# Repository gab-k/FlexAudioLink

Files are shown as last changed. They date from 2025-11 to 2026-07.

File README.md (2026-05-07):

# FlexAudioLink

Low-latency wireless audio bridge.

## Motivation and Use-cases

originally built as a wireless transceiver for a gaming headset retrofit. The hardware can also support:

- Wireless audio relay (e.g. room-to-room)
- BLE audio bridging (phone/laptop as central to a FlexAudioLink node)
- Flexible audio paths such as USB-to-analog, USB-to-USB, analog-to-analog, and BLE bridges

Note: Most of these are not yet implemented; see [Project Status](#project-status).

## Features

- Audio bridge endpoints: USB Audio Class device, I2S/analog codec, BLE
- Low-latency wireless link between devices
- USB CDC CLI for device configuration
- Web UI (Svelte) with WebSerial and WebSocket-to-serial bridge
- Single hardware design: nRF54LM20A + NAU88L21 + nPM1300

## Architecture

The diagram below shows the typical dongle/headset setup: dongle on the left, headset on the right. Both run the same hardware and firmware.

FlexAudioLink wireless headset use case

USB handles audio on the dongle side, I2S/codec on the headset side.

## Project Status

**Implemented:**
- USB device (UAC + CDC)
- Configuration persistence
- USB CDC CLI
- PROP radio test mode
- Audio I2S / codec integration
- Wireless audio streaming (USB ↔ I2S)

**In progress:**
- Schematic
- Update Docs

**Planned:**
- PCB layout
- Arbitrary Source/Sink combinations
- Analog multiplexing
- Packet Loss Concealment
- BLE audio transport
- Web UI

**Under evaluation:**
- Adaptive Frequency Hopping
- Clear Channel Assessment

## Documentation

[**Full documentation**](https://gab-k.github.io/FlexAudioLink/). 

Key pages:

- [**Getting Started**](https://gab-k.github.io/FlexAudioLink/getting-started/) — toolchain setup, build, and flash instructions
- [**Firmware**](https://gab-k.github.io/FlexAudioLink/firmware/) — architecture, PROP protocol
- [**Hardware**](https://gab-k.github.io/FlexAudioLink/hardware/) — schematic, PCB, rationale for chosen components
- [**Web UI**](https://gab-k.github.io/FlexAudioLink/webui/) — setup and configuration
- [**CLI Reference**](https://gab-k.github.io/FlexAudioLink/cli/) — available CLI commands

Note: the documentation is a work in progress and nowhere near complete.

## Repository Layout

- `firmware/`: active Zephyr-based firmware for `nrf54lm20dk/nrf54lm20a/cpuapp`
- `webui/`: Svelte configuration UI plus Python WebSocket-to-serial bridge
- `hardware/`: KiCad project and hardware notes
- `python/`: standalone utilities for signal generation and latency/error experiments
- `devel_notes/`: bring-up and development references

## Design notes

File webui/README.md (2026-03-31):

# FlexAudioLink Web UI

Web-based configuration GUI FlexAudioLink. Communicates with the Hardware over USB CDC ACM serial.

## Prerequisites

- [Node.js](https://nodejs.org/) >= 18
- [pnpm](https://pnpm.io/) (package manager)
- Python 3 with `pyserial` and `websockets` (only for the WebSocket bridge)

## Quick Start

```bash
cd webui/app
pnpm install
pnpm dev
```

Opens at `http://localhost:5173`. Click **Demo Mode** in the status bar to test without hardware.

## Building for Production

```bash
cd webui/app
pnpm build
```

Output goes to `webui/app/dist/`. This is a fully static site deployable to GitHub Pages or any static host.

Preview the production build locally:

```bash
pnpm preview
```

## Connecting to a Device

### Chrome / Edge (WebSerial)

Works out of the box. Click **Connect** in the status bar, then select the dongle serial port from the browser prompt.

### Firefox / Safari (WebSocket Bridge)

These browsers don't support WebSerial. Run the companion bridge script:

```bash
pip install pyserial websockets
python webui/websocket_serial_bridge.py
```

The bridge auto-detects the dongle by USB VID:PID (`1FC9:00A2`). The web app connects to `ws://localhost:8765` automatically when WebSerial is unavailable.

Bridge options:

```
python websocket_serial_bridge.py /dev/ttyACM0   # specify port
python websocket_serial_bridge.py --baud 921600   # custom baud
python websocket_serial_bridge.py --mock           # simulated device
python websocket_serial_bridge.py -v               # show serial traffic
python websocket_serial_bridge.py --list           # list serial ports
```

## Project Structure

```
webui/
  app/                          Svelte frontend
    src/
      main.js                   Entry point
      App.svelte                Shell, tab navigation
      app.css                   Global dark theme
      lib/
        stores/device.svelte.js Reactive device state, protocol parser, config validation
        transport/transport.js  WebSerial / WebSocket / Demo transport abstraction
        components/
          StatusBar.svelte      Connection status, toasts, connect/disconnect buttons
          LinkBudget.svelte     Bitrate budget, TDMA frame viz, latency estimate
        panels/
          ModePanel.svelte      Device role + operating mode selection
          StatusPanel.svelte    Live monitoring (RSSI, battery, packet loss chart)
          AudioPanel.svelte     Speaker/mic settings, EQ, codec selection
          RadioPanel.svelte     PHY rate, TX power, payload/jitter buffer config
          DevicePanel.svelte    Addressing, sleep, persistence (save/load/export/import)
          FirmwarePanel.svelte  DFU instructions with nrfutil commands
          AdvancedPanel.svelte  Raw serial console, live stats, developer shortcuts
    dist/                       Production build output (committed for GitHub Pages)
  websocket_serial_bridge.py    Python WebSocket-to-serial bridge
  spec.md                       Full design specification
```

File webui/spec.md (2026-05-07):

# Wireless Headset Configuration GUI — Design Specification

## Overview

This document describes the design and feature requirements for the web-based configuration GUI for the wireless headset + dongle system. The GUI communicates with the dongle over **USB CDC ACM** (serial) and is the primary interface for end-user configuration, advanced tuning, and firmware updates.

The GUI is delivered as a **hosted web app** (e.g. GitHub Pages) requiring zero installation for most users. It communicates with the dongle via **WebSerial** in Chromium-based browsers, or via a **local WebSocket bridge** for Firefox/Safari users. The actual UI is identical regardless of transport.

---

## Delivery Architecture

### Primary: Hosted Web App (Zero Install)

The GUI is hosted statically on **GitHub Pages** and accessed via a URL. No installation, no download, always up to date.

- Works out of the box in **Chrome, Edge, and other Chromium-based browsers** via the WebSerial API
- User clicks the link, grants serial port permission once, done
- Covers approximately 70% of desktop users

### Fallback: Local WebSocket Bridge (Firefox / Safari)

For browsers that do not support WebSerial (Firefox has no plans to implement it), a minimal companion script bridges the gap.

The bridge is a **single Python file**, runnable with no dependencies beyond PySerial and websockets:

```
pip install pyserial websockets
python websocket_serial_bridge.py
```

Once running, the web app detects WebSerial is unavailable and offers a **"Download Bridge"** button with instructions. The app then connects to `ws://localhost:8765` instead of using WebSerial directly. The protocol is identical either way — the web app does not need to know which transport it is using.

```
Chrome/Edge user:    browser ──WebSerial──────────────────── dongle USB
Firefox user:        browser ──WebSocket──┐
                                          └─ bridge.py ──── dongle USB
```

The bridge script should:
- Auto-detect the dongle by USB VID/PID
- Accept one WebSocket client at a time
- Pass text lines transparently in both directions
- Handle reconnection gracefully if the dongle is unplugged

### Frontend Stack

- **Svelte** — reactive UI with minimal boilerplate, well suited for live-updating meters and graphs
- **uPlot** — high-performance live charting for RSSI, packet loss, and throughput graphs
- **No backend server required** — fully static, GitHub Pages compatible

### Transport Abstraction

The web app should implement a simple transport interface so the rest of the code does not care whether it is talking WebSerial or WebSocket:

```javascript
// transport.js — either backend satisfies this interface
transport.send(textLine)     // sends a plain text string + newline
transport.onMessage(callback) // callback receives raw text lines
transport.connect()
transport.disconnect()
```

On page load, the app checks `navigator.serial` availability and selects the appropriate transport automatically. If neither is available, it shows a clear unsupported browser message with a link to the bridge script.

---

## Architecture Assumptions

- The dongle and headset are **identical hardware** running the **same firmware** — the role is determined entirely by the boot mode setting
- Each device has a **USB-C connector** for firmware updates, configuration, and USB audio mode
- The connected device communicates with the GUI via USB CDC ACM
- Firmware is flashed via **nrfutil** over USB serial (DFU bootloader mode); the GUI cannot flash directly but can trigger DFU mode
- Three boot modes are available: **USB Audio**, **PROP Dongle**, and **PROP Headset**
- The proprietary 2.4 GHz link uses **FHSS + TDMA** with no retransmission — missed packets are concealed via **PLC (Packet Loss Concealment)**
- USB mode turns the device into a wired USB Audio Class device — radio and codec settings do not apply
- The GUI communicates over a simple text-based CLI protocol (newline-delimited commands and responses)

---

## GUI Layout

Suggested tab or panel structure:

```
[ Mode ]  [ Status & Monitor ]  [ Audio Settings ]  [ Radio Settings ]  [ Device Settings ]  [ Firmware Update ]  [ Advanced ]
```

---

## 0. Mode Panel

Configures the fundamental operating mode of the connected device. This panel is shown first as it determines the behavior and available options of all other panels.

| Mode | Description | Effect on Other Panels |
|---|---|---|
| `usb` | Wired USB Audio Class device | Radio panel not applicable, codec settings not applicable |
| `prop_dongle` | PC-side proprietary 2.4 GHz bridge | Full access to applicable Audio and Radio settings |
| `prop_headset` | Headset-side proprietary 2.4 GHz bridge | Full access to applicable Audio and Radio settings |

**Notes:**
- Changing boot mode requires a device restart — warn the user before applying
- Both dongle and headset use the same hardware — the role is part of the persisted firmware mode

---

## 1. Status & Monitor Panel

Read-only live information. Updated on a polling interval (e.g. every 500ms).

### Device Info
- Firmware version (e.g. `v1.2.3`) — same firmware runs on both dongle and headset, role is determined by mode setting
- Peer connected (wireless): Yes / No — whether the other device in the pair is connected

### Battery
- Battery level (percentage)
- Visual battery bar indicator
- Low battery warning threshold (configurable in Device Settings)

### Link Quality
- RSSI (dBm) — live value
- Packet loss % — rolling average over last N seconds (e.g. 5s window)
- Link quality history graph — scrolling chart showing RSSI and packet loss over time (last ~60s)
- TX power currently in use (dBm)

---

## 2. Audio Settings Panel

### Speaker (Headset Output)

| Parameter | Options | Notes |
|---|---|---|
| Sample Rate | 8000, 16000, 24000, 48000, 96000 Hz | Warn if rate strains link budget |
| Bit Width | 8, 16, 24, 32 bit | Configured independently per direction. ADPCM encodes 16-bit samples only and works best up to 48 kHz. (i) tooltip shown always, with ADPCM note appended when ADPCM selected |
| Channels | Mono, Stereo | |
| Codec | PCM (uncompressed), ADPCM, LC3, Opus | See codec notes below |
| Volume | 0–100% slider | Soft volume on headset DSP |
| EQ | 5-band parametric or graphic EQ | Gain per band in dB, ±12dB range |
| Sidetone Level | 0–100% slider (0 = off) | Mic monitoring in ear, latency-critical |

### Microphone (Headset Input → PC)

| Parameter | Options | Notes |
|---|---|---|
| Sample Rate | 8000, 16000, 24000, 48000, 96000 Hz | Voice use cases rarely need >48kHz but 96kHz available for high-fidelity capture |
| Bit Width | 8, 16, 24 bit | Configured independently per direction. (i) tooltip shown always, with ADPCM note appended when ADPCM selected |
| Channels | Mono, Stereo | Stereo mic is niche but include for completeness |
| Codec | PCM, ADPCM, LC3, Opus | Should match or be independently selectable |
| Mic Gain | dB slider or stepped (e.g. 0, 6, 12, 18, 24 dB) | |
| Mic Level Meter | Live VU meter (peak + RMS) | Useful for gain staging |
| Mic Mute | Toggle button | Hardware mute preferred if supported |

### Codec Notes

| Codec | Compression Ratio | Latency Added | Quality | Notes |
|---|---|---|---|---|
| PCM | 1:1 (uncompressed) | 0ms | Perfect | Only viable at lower sample rates / mono on 4Mbps PHY |
| IMA ADPCM | 4:1 | ~0ms | Good (~78dB DR) | Recommended default, trivial complexity |
| LC3 | ~8:1 | 2.5–10ms | Excellent | Good compressed-audio candidate, Nordic SDK supported |
| Opus | Variable | 2.5–20ms | Excellent | Heavier CPU, better for music quality |

**Codec constraints enforced by the GUI:**
- ADPCM: disable bit width options other than 16-bit, cap sample rates at 48 kHz max; (i) tooltip: "ADPCM encodes 16-bit samples only and works best up to 48 kHz. Higher sample rates and other bit depths are not supported."
- LC3: sample rate locked to LC3-supported rates (8k, 16k, 24k, 32k, 48k Hz)
- PCM at 48kHz stereo 16-bit: show red budget warning immediately

### Link Budget Calculator

Displayed prominently below audio settings. Updates in real time as parameters change.

```
Speaker:  48000 Hz × 16 bit × 2 ch ÷ 4 (ADPCM) =  384 kbps
Mic:      48000 Hz × 16 bit × 1 ch ÷ 4 (ADPCM) =  192 kbps
Overhead: (framing, headers, FHSS margin)        =  ~10%
─────────────────────────────────────────────────────────
Total:                                             ~634 kbps
PHY Budget (4Mbps proprietary):                   ~3800 kbps
Headroom:                                          3166 kbps (83%)  ✅
```

- Speaker and mic share the same link pool — the calculator must treat them as a combined load
- Overhead estimate should be conservative (~10–15% for TDMA framing)
- Show a warning banner if headroom < 20%
- Show a hard error and disable "Apply" if calculated load exceeds PHY budget

### TDMA Slot Allocation

Displayed as a visual bar showing how the TDMA frame is divided between downlink (speaker) and uplink (mic). Slot allocation is **dynamic** — proportional to the bitrate ratio of speaker vs mic streams.

- TDMA frame period scales with PHY rate: 2.5ms @ 4Mbps, 5ms @ 2Mbps, 10ms @ 1Mbps
- Slot split is shown as a percentage and in milliseconds
- Updates in real time as audio settings change

### Latency Estimate

Displayed below the TDMA visualization. Shows separate one-way estimates for speaker path (PC → headset ear) and mic path (headset mic → PC). The latency model has two components:

1. **Codec frame accumulation** — zero for PCM/ADPCM (sample-level), 10ms for LC3/Opus (must buffer one full codec frame before encoding)
2. **Jitter buffer** — absorbs TDMA timing variation on the receiver side, depth is **user-configurable** in Radio Settings

Encode/decode processing time is not modeled — it is codec- and hardware-dependent and should be measured on actual hardware.

Each path is shown as a **color-coded pipeline bar** with proportional segment widths. Totals are color-coded: green (<8ms), blue (<20ms), yellow (<35ms), red (>35ms).

**Jitter buffer placement:**
- Speaker path: jitter buffer on the **headset** (receives DL data, buffers before DAC playout)
- Mic path: jitter buffer on the **dongle** (receives UL data, buffers before USB delivery)
- Capacity: configurable 1–50 ms (default: 10 ms)
- **Minimum capacity is clamped to the codec frame size** — the jitter buffer must hold at least one complete codec frame to be decodable. For LC3/Opus (10 ms frames), the minimum jitter buffer is 10 ms. For PCM/ADPCM (sample-level), the minimum is 1 ms.
- **Latency contribution = half the buffer capacity** — the target fill state is always 50% of the buffer. This is the steady-state operating point where there is equal margin to absorb both early and late packets.

**Codec frame accumulation:**

| Codec | Frame accumulation | Min jitter buffer |
|---|---|---|
| PCM | 0 ms | 1 ms |
| ADPCM | 0 ms | 1 ms |
| LC3 | 10 ms | 10 ms |
| Opus | 10 ms | 10 ms |

**Example estimates (frame accumulation + jitter buffer @ 10 ms capacity):**
- PCM/ADPCM @ 10 ms buffer: ~5 ms one-way (jitter buffer latency only: 10/2 = 5 ms)
- LC3/Opus @ 20 ms buffer: ~20 ms one-way (10 ms codec frame + 20/2 = 10 ms jitter buffer)

---

## 3. Radio Settings Panel

The Radio Settings panel includes a **live Link Budget + Latency Estimate** (same component as the Audio panel) so the user can immediately see throughput and latency implications of radio changes (PHY rate, jitter buffer, payload sizes) without switching tabs.

The operating mode (`usb` / `prop_dongle` / `prop_headset`) is selected in the **Mode panel** — the Radio panel shows the relevant settings for the currently active mode. In USB mode, a message indicates that radio settings do not apply.

### Proprietary 2.4 GHz Options

| Parameter | Options | Notes |
|---|---|---|
| PHY Data Rate | 1 Mbps, 2 Mbps, 4 Mbps | Higher = more bandwidth, potentially less range |
| TX Power | -20, -16, -12, -8, -4, 0, +4, +8 dBm | Tradeoff with battery life |
| DL Payload Size | 0.5–50 ms of audio (slider) | Speaker downlink payload in ms. GUI shows computed byte count. Max 252 bytes per packet (nRF54LM20 hw limit). Warns if ms exceeds byte limit for current audio config |
| UL Payload Size | 0.5–50 ms of audio (slider) | Mic uplink payload in ms. Independent from DL — mic and speaker streams may have very different data rates |
| Jitter Buffer | 1–50 ms of audio (slider, default 10 ms) | Receiver-side buffer capacity in ms. Latency contribution = **half the buffer capacity** (target fill state = 50%). Lower = less latency, higher = more robust |
| FHSS Channel Exclusion Map | Checkboxes or range selector per channel | Block persistent interference sources (e.g. specific WiFi channels) |
| FHSS Sequence | Auto (default) / Manual seed | Manual for advanced users |

**Notes:**
- Both payload size and jitter buffer are specified in **milliseconds of audio**, making them independent of sample rate / bit width / codec changes. The GUI computes and displays the resulting byte count for payload size.
- **Payload size is clamped to the jitter buffer capacity** — a payload larger than the buffer cannot be absorbed without overflow, causing guaranteed packet loss. The jitter buffer slider is placed above the payload sliders, and reducing the jitter buffer auto-clamps both DL/UL payloads. (i) tooltips explain this constraint on both payload sliders.
- Switching PHY data rate updates the link budget ceiling dynamically. PHY rate changes require reconnection — warn the user.
- Payload byte limit is constrained by the nRF54LM20 radio hardware: the RADIO LENGTH field is 8 bits, giving a max combined S0+LENGTH+S1+PAYLOAD of 258 bytes. With 2-byte sequence header and packet framing, the usable payload max is **252 bytes**.

## 4. Device Settings Panel

### Device Behavior
- Auto-sleep timeout (minutes): `Off / 5 / 10 / 15 / 30 / 60`
- Low battery warning threshold: `5% / 10% / 15% / 20%`

### Audio I/O
- Audio Interface: `wired` / `usb` / `codec`
- Default is set by firmware based on mode (`wired` for USB, `usb` for PROP dongle, `codec` for PROP headset)
- Setting both devices to CODEC enables analog-to-analog wireless bridging (e.g. airplane 3.5mm jack → wireless → headset)

### Radio Addressing (Proprietary 2.4 GHz)
- Device Address — this device's radio address (read from device on connect, user-editable)
- Peer Address — the address of the other device in the pair (read from device on connect, user-editable)
- Default addresses are set by firmware; the GUI reads them via `get all` on connect
- Only relevant in PROP modes; USB has no radio addressing
- For multiple pairs in the same room, configure unique address pairs to avoid crosstalk

### Persistence
- "Save to device" button — writes current config to NVM on both headset and dongle
- "Load from device" button — reads current config from device
- "Export config to file" — saves a JSON snapshot of all settings locally
- "Import config from file" — loads and applies a previously saved JSON config

---

## 5. Firmware Update Panel

Both devices have **USB-C connectors** and are flashed directly over USB. There is no wireless OTA update path.

### Update Flow
- Current firmware version displayed (from `#S fw=...` status push)
- "Enter DFU Mode" button — sends `reset dfu` to put the device into DFU bootloader
- Step-by-step instructions with copy-pasteable `nrfutil dfu usb-serial` command
- After flashing, device reboots automatically; user reconnects from GUI
- Both dongle and headset use the same firmware — to update the other device, connect it via USB-C and repeat

---

## 6. Advanced Panel

> Intended for developers and power users. Consider hiding behind a toggle or separate menu.

### PHY / Protocol Tuning
- TDMA slot timing (if configurable in firmware)
- PLC algorithm selection (if multiple are implemented — e.g. simple zero-fill vs interpolation)
- Packet size / frame duration

### Debug / Diagnostics
- Raw serial console — read-only log output from dongle/headset via CDC ACM
- Send raw command to device (text field + send button)
- Export diagnostic log to file
- Live statistics table:
  - Packets sent / received / lost (cumulative + per second)
  - RSSI histogram
  - Codec frame errors
  - Buffer underruns / overruns

### Developer Shortcuts
- Trigger headset reboot
- Trigger dongle reboot
- Enter DFU mode manually (without going through Firmware Update panel)
- Read device info dump (chip ID, MAC, build flags)

---

## GUI UX Rules

1. **Always show link budget** — it should be visible any time audio settings are on screen, not buried
2. **Greyed-out invalid options** — don't just warn, actively disable incompatible parameter combinations
3. **Apply vs Auto-apply** — audio parameter changes should require an explicit "Apply" button to avoid mid-stream glitches
4. **Unsaved changes indicator** — show a dot or asterisk in the tab title if there are unapplied or unsaved changes
5. **Connection loss handling** — if dongle disconnects mid-session, show a clear reconnect banner without crashing
6. **Mode indicator** — clearly show when USB mode disables radio controls
7. **No silent failures** — every command sent to the device should have a visible success/failure response in a status bar

---

## Serial Protocol (CDC ACM) — Text-Based CLI

The device exposes a human-readable CLI over USB CDC ACM. The same commands work identically from a terminal emulator (minicom/screen) and from the web GUI. All commands and responses are **newline-terminated plain text**.

### Commands (Host → Device)

```
get <param>              # get single param: get volume
get <group>              # get group: get audio, get radio, get device, get mode
get all                  # get everything
set <param> <value>      # set volume 80, set codec_spk adpcm
status                   # one-shot status snapshot
status on [<ms>]         # start periodic status push (default 500ms)
status off               # stop periodic push
echo on|off              # enable/disable local echo (GUI sends "echo off" on connect)
help, reset, scan, linktest  # existing firmware CLI commands, unchanged
```

Commands are **case-insensitive**. The `target` concept (dongle/headset) is gone — the firmware knows which subsystem owns each parameter.

### Responses (Device → Host)

| Pattern | Meaning | Example |
|---|---|---|
| `OK param=value` | Set succeeded | `OK volume=80` |
| `ERR param reason` | Set failed | `ERR codec_spk invalid value "mp3"` |
| `key=value` | Get response (one per line) | `volume=80` |
| `[groupname]` | Group header (human readability aid, GUI ignores) | `[audio]` |
| `#S key=val key=val ...` | Periodic status push (space-separated) | `#S rssi=-62 bat=87 loss=0.1 conn=yes` |
| anything else | Raw console text | Passed to debug console in Advanced panel |

### Status Push Abbreviated Keys

| Key | Meaning |
|---|---|
| `rssi` | RSSI in dBm |
| `bat` | Battery percentage |
| `loss` | Packet loss percentage |
| `conn` | Peer connected (yes/no) |
| `tx` | Packets transmitted (cumulative) |
| `rx` | Packets received (cumulative) |
| `lost` | Packets lost (cumulative) |
| `urun` | Buffer underruns |
| `orun` | Buffer overruns |
| `cerr` | Codec errors |
| `fw` | Firmware version |

### Parameter Table

| Parameter | Group | Type | Values |
|---|---|---|---|
| `sample_rate_spk` | audio | int | 8000..96000 |
| `bit_width_spk` | audio | int | 8,16,24,32 |
| `channels_spk` | audio | string | mono,stereo |
| `codec_spk` | audio | string | pcm,adpcm,lc3,opus |
| `volume` | audio | int | 0..100 |
| `sidetone` | audio | int | 0..100 |
| `sample_rate_mic` | audio | int | 8000..96000 |
| `bit_width_mic` | audio | int | 8,16,24 |
| `channels_mic` | audio | string | mono,stereo |
| `codec_mic` | audio | string | pcm,adpcm,lc3,opus |
| `mic_gain` | audio | int | 0..60 |
| `mic_mute` | audio | bool | on/off |
| `eq` | audio | special | `set eq <band> <freq> <gain>`, get returns `eq0=100,0` etc. |
| `phy_rate` | radio | int | 1,2,4 |
| `tx_power` | radio | int | -20..8 |
| `fhss_exclusion` | radio | list | comma-separated ints or `none` |
| `payload_ms_dl` | radio | float | 0.5..50 |
| `payload_ms_ul` | radio | float | 0.5..50 |
| `jitter_buffer_ms` | radio | float | 1..100 |
| `audio_io` | device | string | wired,usb,codec |
| `device_addr` | radio | hex | 4-byte address, e.g. `0xD0D0D0D0` |
| `peer_addr` | radio | hex | 4-byte address of peer device |
| `mode` | mode | string | usb,prop_dongle,prop_headset |
| `auto_sleep` | device | int | 0..60 |
| `low_battery_threshold` | device | int | 0..100 |

### GUI Connect Sequence

On successful serial/WebSocket connection, the GUI sends:

```
echo off
status on 500
get all
```

This suppresses local echo, starts periodic status pushes at 500ms, and requests the full current configuration.

---

## Out of Scope for v1

- Mobile app / BLE configuration (considered v2)
- Cloud firmware hosting / auto-update checking
- Multi-device management (more than one headset)
- Per-application audio modes (OS-level integration)
- Noise cancellation controls (requires DSP firmware support)
- Native desktop app (Tauri/Electron) — the web app + bridge covers all use cases without the complexity

---

## Open Questions / To Be Decided in Firmware

- Which PLC algorithm(s) will be implemented?
- Is sidetone processed on the headset CODEC or in firmware?
- Are EQ coefficients computed on-device or sent as pre-calculated biquad coefficients from the GUI?
- What is the exact TDMA frame duration and how does that map to minimum/maximum configurable latency?
- Is there a hardware mute button on the headset, and does it report state back over the wireless link?

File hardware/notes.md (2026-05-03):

# Hardware Notes

## ICs
- **SoC** nRF54LM20A-PAAA (CSP47)
- **Codec** NAU88L21 (QFN32)
- **PMIC** nPM1300-QEAA
- **Battery protection** DW01A + FS8205

---

## Power Rails
| Rail | Source | Voltage | Load |
|---|---|---|---|
| Buck 1 (VOUT1) | VBAT/VBUS | 1.8V | nRF VDD, codec VDDB |
| Buck 2 (VOUT2) | VBAT/VBUS | 3.3V | codec VDDMIC, LDO1 in |
| LDO 1 | Buck 2 | 1.8V | codec VDDA |
| LDO 2 | Buck 2 | TBD | touch IC / reserved |

---

## nRF54LM20A — Schematic Reminders
- DC-DC: DCC node → **L1 4.7µH 0603**
- VDD bulk: **C4 10µF 0402** + **C5 100nF 0201**
- VDD decoupling: **C1, C2, C10 100nF 0201**
- DECA: **FB1 0201** + **FB2 0201** (two ferrites in DK) + **C6 4.7µF** to VSS
- DECD: **C14 2.2µF 0201** to VSS
- DECRF: **L5 1.0nH** + **C8 1.0pF** + **C7 2.2µF** (DK fits C7, ref design marks N.C.)
- DECUSB: **C10 2.2µF + C11 4.7µF**
- USB VBUS: **R1 2R2 0603** in series; ESD protection PRTR5V0U2F + CMC DLM0NSM900HY2D on D+/D−
- TRXTUNE: **R2 200R 0603** to VSS
- 32MHz XO: XTAL_2016 (X1)
- 32.768kHz XO: XTAL_2012 (X2) — optional
- RF match: L2 3.6nH, L3 4.7nH, L4 3.3nH, C3 1.2pF, C12 1.5pF, C13 N.C.

## nRF54LM20A — Layout Reminders
- Follow Nordic reference: **13.11 × 12.00mm**, 8-layer, 1.57mm total
- RF matching as close as possible to ANT pin
- DECRF caps closest to IC, then L5
- DECA/DECD/DCC passives same side as IC, short traces
- P2 is high-speed port — follow Nordic HDI rules

---

## NAU88L21 — Schematic Reminders
- VDDA: 1.8V from LDO1 (max 1.98V — do not exceed)
- VDDB: 1.8V from Buck 1
- VDDMIC: 3.3V from Buck 2
- VREF: **4.7µF** low-leakage cap to VSSA
- Charge pump caps: **3× 2µF ceramic** (CPCA–CPCB, CPOUTP, CPOUTN)
- Mic inputs: AC-coupled differential
- I2S to nRF: BCLK, FS, DACIN, ADCOUT
- I2C to nRF: SCLK, SDIO (codec is slave)
- GPIO1/CSB: pull low → I2C addr 0x1B, pull high → 0x54

---

## nPM1300 — Schematic Reminders
- Buck inductors: **L6, L7 = 2.2µH** (one per buck)
- VSET1: **47k** → 1.8V startup
- VSET2: **4.7k** → 1.8V startup (change for 3.3V per resistor table)
- VSYS bulk: **4× 10µF** caps (PVSS1 and PVSS2, via to GND plane on each)
- VOUT1 decoupling: **10µF + 100nF**
- VOUT2 decoupling: **10µF + 100nF**
- VBUS input: **4.7µF + 100nF**; ferrite bead FB on VBUS line
- CC1/CC2: wire directly to USB-C connector + **1.0nF cap to GND** on each
- NTC pin: connect battery thermistor (10k NTC recommended)
- VBAT: via DW01A + FS8205 from cell
- VDDIO: connect to Buck 1 output (1.8V)
- nPM1300 communicates with nRF via I2C (SCL/SDA)

---

## Battery Protection (DW01A + FS8205)
- Cell+ → DW01A → FS8205 → VBAT (nPM1300)
- Skip if using cell with integrated protection PCB

---

## USB-C Connector
- VBUS → ferrite bead (120R/3A) → nPM1300 VBUS
- VBUS → R1 2R2 → nRF VBUS pin
- CC1/CC2 → nPM1300 CC1/CC2 (+ 1.0nF to GND each)
- D+/D− → ESD + CMC → nRF P2 (high-speed port)
- R45/R46 5k1 on CC lines only needed if doing USB-C orientation detection at nRF — not required for basic charging

---

## Codec Audio Path
- Headphone out: HPL/HPR ground-referenced, cap-free
- Mic in: MICL+/− or MICR+/− AC-coupled differential
- Digital mic alt: MICR−/DMCLK + MICL−/DMDATA

---

## Analog Multiplexing

To support arbitrary Source/Sink configurations on the 3.5 mm jack, the physical connector needs to be routable to either the codec's DAC output (headphone driver) or ADC input (mic stage) under firmware control.

### Option 1 — Cable adapter (early prototyping)
- Route the source's headphone out to the codec's mic input via a custom cable.
- No hardware changes required.
- Caveats: shifts burden to the user, mic input impedance/gain is not ideal for line-level signals, inconsistent with the "same hardware, different roles" design goal.

### Option 2 — Analog switch IC (production)
- Add analog multiplexer between the 3.5 mm jack and the codec's audio pins.
- Firmware controls the switch via GPIO to swap the jack between HPL/HPR (DAC out) and MICL+/MICR+ (ADC in).
- Combined with I2S stream routing in firmware, any audio endpoint becomes reconfigurable as source or sink.

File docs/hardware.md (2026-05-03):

# Hardware

The `hardware/` directory currently contains early hardware notes and KiCad work-in-progress.

## Target Design

The current design plan is based on:

| Component | Description |
|---|---|
| nRF54LM20A | Nordic SoC with BLE and proprietary radio |
| NAU88L21 | Audio codec |
| nPM1300 | PMIC |

!!! note
    Hardware is in early concept stage, subject to change.

## Schematic & Layout

KiCad project files are in `hardware/`. Refer to the schematic and layout for pin assignments and component details.

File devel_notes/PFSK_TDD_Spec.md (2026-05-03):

# PFSK Time Division Duplex Spec

Implementation reference: `firmware/src/prop_fsk/`.

- `radio_core.c`:

	authoritative for radio timing and DMA ownership.
	Its entirely Timer/[DPPI](https://docs.nordicsemi.com/bundle/ps_nrf54LM20A/page/dppi.html) and ISR based.

- `session.c`:

	is authoritative for service state, app queues, payload sequencing, and loss accounting.

## Protocol

- Both peers run identical half-duplex ping-pong logic.
- No role-specific slot timing exists.
- Device waits for RX to be done then sends itself, then listens again.
- A TX turn always sends either one queued payload packet or one keepalive.
- Listen timeouts include random jitter; the first peer to time out transmits, breaking deadlock.

## Relevant RADIO Peripheral Events

Reference: [nRF RADIO peripheral docs](https://docs.nordicsemi.com/bundle/ps_nrf54LM20A/page/radio.html)

| Event | Meaning |
|---|---|
| `ADDRESS` | Address field sent or matched |
| `PHYEND` | Full packet (including CRC) transmitted or received |
| `CRCOK` | Received packet CRC matched |
| `CRCERROR` | Received packet CRC failed |

Handled inside `radio_isr`.

## Radio Turn State

Active protocol states:

| State | Meaning |
|---|---|
| `LISTEN` | Radio waits for peer `ADDRESS` or listen deadline. |
| `IN_RX` | Peer packet has reached `ADDRESS`; RX deadline is armed. |
| `IN_TX` | Local TX has been committed; late peer `ADDRESS` is ignored. |

Implementation sentinel:

| State | Meaning |
|---|---|
| `DISABLED` | Radio path stopped; not a protocol turn. |

## Session Events

`radio_core` emits one ordered event stream to `session.c`.

```c
struct pfsk_session_event {
	enum pfsk_session_event_type type;
	uint32_t tick;
	int16_t rssi_dbm;
};
```

| Event | Tick | Notes |
|---|---|---|
| `RX_OK` | RX `PHYEND` | RSSI valid. |
| `RX_BAD` | RX `PHYEND` | RSSI valid. |
| `TX_END` | TX `PHYEND` | TX already ended. |
| `RX_INCOMPLETE` | deadline | RX packet did not finish in time. |
| `LISTEN_TIMEOUT` | deadline | No peer `ADDRESS` before deadline. |
| `TX_TRIGGER_FAILED` | deadline | Timeout TX could not be triggered. |

## Packet Format

Packet struct:

```c
struct pfsk_packet {
	uint8_t  length;
	uint16_t seq;
	uint8_t  payload[PFSK_PAYLOAD_MAX_LEN];
} __packed __aligned(4);
```

- packets never use `seq = PFSK_KEEPALIVE_SEQ = UINT16_MAX` unless they are keepalive packets.
- zero-length app TX frames are invalid

Constants:
- `PFSK_PACKET_METADATA_LEN = 2U`
- `PFSK_PAYLOAD_MAX_LEN = 252`
- `PFSK_KEEPALIVE_PAYLOAD_LEN = 16U`
- `PFSK_KEEPALIVE_SEQ = UINT16_MAX`

Note: Do not confuse `payload` inside `struct pfsk_packet` with `PAYLOAD` field inside [nRF RADIO Peripheral docs -> Packet configuration](https://docs.nordicsemi.com/bundle/ps_nrf54LM20A/page/radio.html#ariaid-title2)

## Buffers

`radio_core.c` owns the packet buffers. `PACKETPTR` always points to the
current read/write slot in these rings. The RADIO peripheral DMA transfers
directly to/from the pointed-to ring entry.

```c
tx_ring[PFSK_RADIO_TX_RING_DEPTH]
rx_ring[PFSK_RADIO_RX_RING_DEPTH]
keepalive_packet
```

Ring ownership:

| Ring index | Writer |
|---|---|
| TX write | session thread |
| TX read | radio ISR |
| RX write | radio ISR |
| RX read | session thread |

Rings are Single Producer Single Consumer (SPSC). One slot remains unused to distinguish full from empty.

TX ring rules:

- TX ring contains payload packets only.
- Keepalives are never queued in the TX ring.
- Session gets a pointer to the next TX slot via `pfsk_radio_tx_get_wr_ptr()`,
  copies into it, then commits with `pfsk_radio_tx_advance_wr_idx()`.
- Session-thread does not touch `PACKETPTR`.

RX ring rules:

- RADIO DMA writes to `rx_ring[rx_wr_idx]`.
- `CRCOK`/`CRCERROR` queues a session event.
- RX write index advances only if the RX ring has room and event queueing succeeds.
- Session releases a consumed RX slot with `pfsk_radio_rx_advance_rd_idx()`.

## RADIO Shortcuts

Reference: [nRF RADIO peripheral docs -> SHORTS register](https://docs.nordicsemi.com/bundle/ps_nrf54LM20A/page/radio.html#ariaid-title112)

Base shorts (always active):

- `READY_START` - READY -> START: begin TX/RX as soon as ramp-up completes.
- `PHYEND_DISABLE` - PHYEND -> DISABLE: shut down radio after every packet.
- `ADDRESS_RSSISTART` - ADDRESS -> RSSISTART: sample signal strength on peer packet arrival.

Turn-selection shorts (one active at a time):

- `DISABLED_RXEN` - DISABLED -> RXEN: after disable, ramp back into RX.
- `DISABLED_TXEN` - DISABLED -> TXEN: after disable, ramp into TX.

`PHYEND_DISABLE` + a turn-selection short chains the whole turnaround in hardware:
packet ends -> radio disables -> radio re-enables in the next direction, no ISR needed.

The active shortcut set prepares the *next* direction:

- while receiving: `BASE | DISABLED_TXEN` (turnaround into TX)
- while transmitting: `BASE | DISABLED_RXEN` (turnaround into RX)

## PACKETPTR and Shortcut Programming

PACKETPTR and shortcuts are always set together. Programming an RX pointer selects `DISABLED_TXEN`, programming a TX pointer selects `DISABLED_RXEN`.

RX programming:

```text
PACKETPTR = &rx_ring[rx_wr_idx]
```

TX programming:

```text
PACKETPTR = &tx_ring[tx_rd_idx]   if TX ring non-empty
PACKETPTR = &keepalive_packet     if TX ring empty
```

Programming points:

| Point | Action |
|---|---|
| `pfsk_radio_start()` | Program initial RX pointer. |
| `ADDRESS` while `LISTEN` | Program next TX pointer. |
| `LISTEN`/`IN_RX` timeout | Program TX pointer directly before switchover to TX. |
| `ADDRESS` while `IN_TX` | Program next RX pointer. |

## Deadlines

Timer:

- TIMER10 runs at 1 MHz.
- CC[2] captures `ADDRESS`.
- CC[3] is the semantic deadline compare.
- CC[4] captures `PHYEND`.

Constants:
- `PFSK_RADIO_LISTEN_TIMEOUT_BASE_US` — fixed listen window before timeout.
- `PFSK_RADIO_LISTEN_TIMEOUT_JITTER_US` — max random offset added to listen timeout. Determined by xorshift PRNG seeded from device ID and cycle counter.
- `PFSK_RADIO_MAX_PACKET_AIRTIME_US` — worst-case packet duration on air.
- `PFSK_RADIO_DEADLINE_MIN_LEAD_US` — minimum time a deadline must be in the future.

Deadline rules:

| Entry | Deadline |
|---|---|
| start -> `LISTEN` | `now + BASE_US + jitter` |
| `ADDRESS` -> `IN_RX` | `address_tick + MAX_PACKET_AIRTIME_US` |
| TX `PHYEND` -> `LISTEN` | `tx_phyend_tick + MAX_PACKET_AIRTIME_US + jitter` |

If a deadline is too close, `radio_core` clamps it forward by
`DEADLINE_MIN_LEAD_US` and increments `deadline_late_count`.

TX ring publication never changes deadlines.

## State Transitions

### `LISTEN -> IN_RX`

Trigger: RADIO `ADDRESS`.

Actions:

- set `turn_state = IN_RX`
- arm RX deadline
- program TX `PACKETPTR` to TX ring head or keepalive

### `LISTEN -> IN_TX`

Trigger: listen timeout deadline.

Actions:

- queue `LISTEN_TIMEOUT`
- program TX `PACKETPTR` to TX ring head or keepalive
- set shorts to `DISABLED_TXEN`
- clear pending `ADDRESS`, RX ADDRESS could arrive between timeout and `DISABLE`
- set `turn_state = IN_TX`
- trigger RADIO `DISABLE`
- if trigger fails, queue `TX_TRIGGER_FAILED`

### `IN_RX -> IN_TX`

Triggers:

- RX `PHYEND`, after `CRCOK`/`CRCERROR`
- RX timeout deadline

RX `PHYEND` actions:

- `CRCOK` queues `RX_OK`; `CRCERROR` queues `RX_BAD`
- RX write index advances if event queueing succeeds
- `PHYEND` handler sets `turn_state = IN_TX`
- hardware short starts TX

RX timeout deadline actions:

- queue `RX_INCOMPLETE`
- program TX `PACKETPTR` to TX ring head or keepalive
- set shorts to `DISABLED_TXEN`
- clear pending `ADDRESS`, RX ADDRESS could arrive between timeout and `DISABLE`
- set `turn_state = IN_TX`
- trigger RADIO `DISABLE`
- if trigger fails, queue `TX_TRIGGER_FAILED`

### `IN_TX -> LISTEN`

Trigger: TX `PHYEND`.

Actions:

- advance TX read index only if the transmitted packet came from TX ring buffer
- set `turn_state = LISTEN`
- arm post-TX listen deadline
- increment TX stats
- queue `TX_END`

`TX_END` is queued from `PHYEND`, not from `DISABLED`. The next RX pointer was
already programmed by TX `ADDRESS`.

## Session Handling

`RX_OK`:

- read RX packet from RX ring
- reject malformed length and advance RX read index (early return)
- reset `consecutive_rx_misses`
- enter `IN_SERVICE`
- if keepalive marker: no app frame, no seq accounting
- if payload: queue app RX frame and update seq/loss accounting
- advance RX read index

`RX_BAD`:

- reset `consecutive_rx_misses`
- advance RX ring buffer read index
- do not enter service from `NO_SERVICE`

`RX_INCOMPLETE`:

- increment `rx_incomplete_count`
- reset `consecutive_rx_misses`

`LISTEN_TIMEOUT`:

- if `IN_SERVICE`, increment `consecutive_rx_misses`
- if threshold reached, mark `NO_SERVICE`
- if already `NO_SERVICE`, log rate-limited waiting warning

`TX_END`:

- refill TX ring with queued payloads until full or app TX queue empty

`TX_TRIGGER_FAILED`:

- increment `tx_trigger_fail_count`
- mark `NO_SERVICE`
- log error
- stop radio path

## Service State

States:

- `NO_SERVICE`
- `IN_SERVICE`

Enter service:

- valid `RX_OK` packet, including keepalive

Stay in service:

- `RX_OK`, `RX_BAD`, and `RX_INCOMPLETE` all reset misses
- `RX_BAD` and `RX_INCOMPLETE` reset misses but do not enter service on their own

Leave service:

- only consecutive `LISTEN_TIMEOUT` events count as missed peer activity
- threshold is `PFSK_SESSION_SYNC_LOSS_TURNS`

On service loss:

- increment outage counter if previously in service
- reset miss counter
- clear in-service timestamp
- clear RX sequence continuity
- do not reset radio turn state

## Responsibilities

`radio_core` owns:

- RADIO/TIMER configuration
- turn state
- deadlines and jitter
- `PACKETPTR` and shorts
- RX/TX rings
- keepalive fallback packet
- session event queue
- hardware stats

`session.c` owns:

- service state
- app TX/RX queues
- payload copy into TX ring
- payload sequence/loss accounting
- user-visible session stats/logs

## Invariants

1. Both roles use identical timing logic.
2. `PHYEND` anchors packet end.
3. `ADDRESS` is the only peer packet start gate.
4. `FRAMESTART` and `SYNC` are not protocol inputs.
5. `session.c` does not own radio turn state.
6. Session events do not carry packet payloads.
7. TX ring entries are payload-only.
8. Empty TX ring means transmit `keepalive_packet`.
9. Keepalive does not consume payload sequence numbers.
10. Payload sequence generation skips `PFSK_KEEPALIVE_SEQ`.
11. Session-thread TX publication does not program `PACKETPTR`.
12. `PACKETPTR` and turn-selection shortcut are always programmed together.
13. `ADDRESS` must program the next-direction `PACKETPTR` before `PHYEND` fires.
14. Only `RX_OK` can enter service; `RX_BAD` and `RX_INCOMPLETE` cannot.
15. Listen timeout is a hard turn boundary.
16. Stop purges stale session events and leaves radio state disabled.

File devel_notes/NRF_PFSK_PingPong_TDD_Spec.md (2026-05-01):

# nRF PFSK Ping-Pong TDD Spec

Implementation reference: `firmware/src/prop_fsk/`.

`radio_core.c` is authoritative for radio timing and DMA ownership. `session.c`
is authoritative for service state, app queues, payload sequencing, and loss
accounting.

## Protocol

- Both peers run identical half-duplex ping-pong logic.
- `ADDRESS` is the only early RX-start gate.
- `PHYEND` is the packet-end timing anchor.
- `FRAMESTART` and `SYNC` are not used for core state transitions.
- No role-specific slot timing exists.
- A TX turn always sends either one queued payload packet or one keepalive.

## Radio Turn State

Active protocol states:

| State | Meaning |
|---|---|
| `LISTEN` | Radio waits for peer `ADDRESS` or listen deadline. |
| `IN_RX` | Peer packet has reached `ADDRESS`; RX deadline is armed. |
| `IN_TX` | Local TX has been committed; late peer `ADDRESS` is ignored. |

Implementation sentinel:

| State | Meaning |
|---|---|
| `DISABLED` | Radio path stopped; not a protocol turn. |

`session.c` must not duplicate this state machine.

## Radio Events

`radio_core` emits one ordered metadata-only event stream to `session.c`.

```c
struct pfsk_radio_event {
	enum pfsk_radio_event_type type;
	uint32_t tick;
	int16_t rssi_dbm;
};
```

Events never carry packets. RX packets are read from the RX ring.

| Event | Tick | Notes |
|---|---|---|
| `RX_OK` | RX `PHYEND` | RSSI valid. |
| `RX_BAD` | RX `PHYEND` | RSSI valid. |
| `TX_END` | TX `PHYEND` | TX already ended. |
| `RX_INCOMPLETE` | deadline | RX packet did not finish in time. |
| `LISTEN_TIMEOUT` | deadline | No peer `ADDRESS` before deadline. |
| `TX_TRIGGER_FAILED` | deadline | Timeout TX could not be triggered. |

## Packet Format

RADIO config:

- `lflen = 8`
- `s0len = 0`
- `s1len = 0`

DMA buffer:

```text
offset 0:    LENGTH byte
offset 1..N: PAYLOAD bytes, N = LENGTH
```

Packet struct:

```c
struct pfsk_packet {
	uint8_t  length;
	uint16_t seq;
	uint8_t  data[PFSK_PAYLOAD_MAX_LEN];
} __packed __aligned(4);
```

Constants:

- `PFSK_PACKET_METADATA_LEN = 2U`
- `PFSK_PAYLOAD_MAX_LEN = 252`
- max transmitted `length = 254`
- `PFSK_KEEPALIVE_PAYLOAD_LEN = 16U`
- `PFSK_KEEPALIVE_SEQ = UINT16_MAX`
- `PFSK_KEEPALIVE_LEN = PFSK_PACKET_METADATA_LEN + PFSK_KEEPALIVE_PAYLOAD_LEN`
- keepalive `length = PFSK_KEEPALIVE_LEN`
- payload packets never use `PFSK_KEEPALIVE_SEQ`
- zero-length app TX frames are invalid

## Buffers

`radio_core.c` owns the packet buffers:

```c
g_tx_ring[PFSK_RADIO_TX_RING_DEPTH]
g_rx_ring[PFSK_RADIO_RX_RING_DEPTH]
g_keepalive_packet
```

Ring ownership:

| Ring index | Writer |
|---|---|
| TX write | session thread |
| TX read | radio ISR |
| RX write | radio ISR |
| RX read | session thread |

Rings are SPSC. One slot remains unused to distinguish full from empty.

TX ring rules:

- TX ring contains payload packets only.
- Keepalives are never queued in the TX ring.
- Session publishes a payload by filling `pfsk_radio_tx_get_wr_ptr()` and then
  calling `pfsk_radio_tx_advance_wr_idx()`.
- Session-thread publication does not touch `PACKETPTR`.

RX ring rules:

- RADIO DMA writes to `g_rx_ring[g_rx_wr_idx]`.
- `CRCOK`/`CRCERROR` queues a metadata-only event.
- RX write index advances only if the RX ring has room and event queueing
  succeeds.
- Session releases a consumed RX slot with `pfsk_radio_rx_advance_rd_idx()`.

## RADIO Shortcuts

Base shorts:

- `READY_START`
- `PHYEND_DISABLE`
- `ADDRESS_RSSISTART`

Turn-selection shorts:

- `DISABLED_RXEN`
- `DISABLED_TXEN`

The active shortcut set is:

- RX path: `BASE | DISABLED_RXEN`
- TX path: `BASE | DISABLED_TXEN`

## PACKETPTR Rules

RX programming:

```text
PACKETPTR = &g_rx_ring[g_rx_wr_idx]
```

TX programming:

```text
PACKETPTR = &g_tx_ring[g_tx_rd_idx] if TX ring non-empty
PACKETPTR = &g_keepalive_packet     if TX ring empty
```

Programming points:

| Point | Action |
|---|---|
| `pfsk_radio_start()` | Program initial RX pointer. |
| `ADDRESS` while `LISTEN` | Program next TX pointer. |
| `LISTEN`/`IN_RX` timeout | Program TX pointer directly before switchover to TX. |
| `ADDRESS` while `IN_TX` | Program next RX pointer. |

## Deadlines

Timer:

- TIMER10 runs at 1 MHz.
- CC[2] captures `ADDRESS`.
- CC[3] is the semantic deadline compare.
- CC[4] captures `PHYEND`.

Deadline rules:

| Entry | Deadline |
|---|---|
| start -> `LISTEN` | `now + BASE_US + jitter` |
| `ADDRESS` -> `IN_RX` | `address_tick + MAX_PACKET_AIRTIME_US` |
| TX `PHYEND` -> `LISTEN` | `tx_phyend_tick + MAX_PACKET_AIRTIME_US + jitter` |

`radio_core` clamps too-late deadlines forward by
`PFSK_RADIO_DEADLINE_MIN_LEAD_US` and increments `deadline_late_count`.

TX ring publication never changes deadlines.

## State Transitions

### `LISTEN -> IN_RX`

Trigger: RADIO `ADDRESS`.

Actions:

- set `turn_state = IN_RX`
- arm RX deadline
- program TX `PACKETPTR` to TX ring head or keepalive
- set shorts to `BASE | DISABLED_TXEN`

### `LISTEN -> IN_TX`

Trigger: listen timeout deadline.

Actions:

- queue `LISTEN_TIMEOUT`
- program TX `PACKETPTR` to TX ring head or keepalive
- clear pending `ADDRESS`
- set `turn_state = IN_TX`
- trigger RADIO `DISABLE`
- if trigger fails, queue `TX_TRIGGER_FAILED`

### `IN_RX -> IN_TX`

Triggers:

- RX `PHYEND`, after `CRCOK`/`CRCERROR`
- RX timeout deadline

RX `PHYEND` actions:

- `CRCOK` queues `RX_OK`; `CRCERROR` queues `RX_BAD`
- RX write index advances if event queueing succeeds
- `PHYEND` handler sets `turn_state = IN_TX`
- hardware short starts TX

RX timeout deadline actions:

- queue `RX_INCOMPLETE`
- program TX pointer
- set `turn_state = IN_TX`
- trigger RADIO `DISABLE`

### `IN_TX -> LISTEN`

Trigger: TX `PHYEND`.

Actions:

- advance TX read index only if the transmitted packet came from TX ring buffer
- set `turn_state = LISTEN`
- arm post-TX listen deadline
- increment TX stats
- queue `TX_END`

`TX_END` is queued from `PHYEND`, not from `DISABLED`. The next RX pointer was
already programmed by TX `ADDRESS`.

## Session Handling

`RX_OK`:

- read RX packet from RX ring
- reject malformed length and release slot
- reset `consecutive_rx_misses`
- enter `IN_SERVICE`
- if keepalive marker: no app frame, no seq accounting
- if payload: queue app RX frame and update seq/loss accounting
- release RX slot

`RX_BAD`:

- reset `consecutive_rx_misses`
- release RX slot
- do not enter service from `NO_SERVICE`

`RX_INCOMPLETE`:

- increment `rx_incomplete_count`
- reset `consecutive_rx_misses`

`LISTEN_TIMEOUT`:

- if `IN_SERVICE`, increment `consecutive_rx_misses`
- if threshold reached, mark `NO_SERVICE`
- if already `NO_SERVICE`, log rate-limited waiting warning

`TX_END`:

- refill TX ring with queued payloads until full or app TX queue empty

`TX_TRIGGER_FAILED`:

- increment `tx_trigger_fail_count`
- mark `NO_SERVICE`
- log error
- stop radio path

## Service State

External states:

- `NO_SERVICE`
- `IN_SERVICE`

Enter service:

- valid `RX_OK` packet, including keepalive

Stay in service:

- `RX_OK`, `RX_BAD`, and `RX_INCOMPLETE` all reset misses

Leave service:

- only consecutive `LISTEN_TIMEOUT` events count as missed peer activity
- threshold is `PFSK_SESSION_SYNC_LOSS_TURNS`

On service loss:

- increment outage counter if previously in service
- reset miss counter
- clear in-service timestamp
- clear RX sequence continuity
- do not reset radio turn state

## Responsibilities

`radio_core` owns:

- RADIO/TIMER configuration
- turn state
- deadlines and jitter
- `PACKETPTR` and shorts
- RX/TX rings
- keepalive fallback packet
- metadata-only radio event queue
- hardware stats

`session.c` owns:

- service state
- app TX/RX queues
- payload copy into TX ring
- payload sequence/loss accounting
- keepalive RX policy
- user-visible session stats/logs

## Invariants

1. Both roles use identical timing logic.
2. `PHYEND` anchors packet end.
3. `ADDRESS` is the only peer packet start gate.
4. `FRAMESTART` and `SYNC` are not protocol inputs.
5. `session.c` does not own radio turn state.
6. RX events do not carry packet payloads.
7. TX ring entries are payload-only.
8. Empty TX ring means transmit `g_keepalive_packet`.
9. Keepalive does not consume payload sequence numbers.
10. Payload sequence generation skips `PFSK_KEEPALIVE_SEQ`.
11. Session-thread TX publication does not program `PACKETPTR`.
12. Listen timeout is a hard turn boundary.
13. Stop purges stale radio events and leaves radio state disabled.

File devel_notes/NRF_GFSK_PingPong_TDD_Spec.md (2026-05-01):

# nRF GFSK Ping-Pong TDD Spec

Implementation reference: `firmware/src/prop_gfsk/`.

`radio_hw.c` is authoritative for radio timing and DMA ownership. `link.c`
is authoritative for service state, app queues, payload sequencing, and loss
accounting.

## Protocol

- Both peers run identical half-duplex ping-pong logic.
- `ADDRESS` is the only early RX-start gate.
- `PHYEND` is the packet-end timing anchor.
- `FRAMESTART` and `SYNC` are not used for core state transitions.
- No role-specific slot timing exists.
- A TX turn always sends either one queued payload packet or one keepalive.

## Hardware Turn State

Active protocol states:

| State | Meaning |
|---|---|
| `LISTEN` | Radio waits for peer `ADDRESS` or listen deadline. |
| `IN_RX` | Peer packet has reached `ADDRESS`; RX deadline is armed. |
| `IN_TX` | Local TX has been committed; late peer `ADDRESS` is ignored. |

Implementation sentinel:

| State | Meaning |
|---|---|
| `DISABLED` | Radio path stopped; not a protocol turn. |

`link.c` must not duplicate this state machine.

## Hardware Events

`radio_hw` emits one ordered metadata-only event stream to `link.c`.

```c
struct pgfsk_hw_event {
	enum pgfsk_hw_event_type type;
	uint32_t tick;
	int16_t rssi_dbm;
};
```

Events never carry packets. RX packets are read from the RX ring.

| Event | Tick | Notes |
|---|---|---|
| `RX_OK` | RX `PHYEND` | RSSI valid. |
| `RX_BAD` | RX `PHYEND` | RSSI valid. |
| `TX_END` | TX `PHYEND` | TX already ended. |
| `RX_INCOMPLETE` | deadline | RX packet did not finish in time. |
| `LISTEN_TIMEOUT` | deadline | No peer `ADDRESS` before deadline. |
| `TX_TRIGGER_FAILED` | deadline | Timeout TX could not be triggered. |

## Packet Format

RADIO config:

- `lflen = 8`
- `s0len = 0`
- `s1len = 0`

DMA buffer:

```text
offset 0:    LENGTH byte
offset 1..N: PAYLOAD bytes, N = LENGTH
```

Packet struct:

```c
struct pgfsk_packet {
	uint8_t  length;
	uint16_t seq;
	uint8_t  data[PGFSK_PAYLOAD_MAX_LEN];
} __packed __aligned(4);
```

Constants:

- `PGFSK_PACKET_METADATA_LEN = 2U`
- `PGFSK_PAYLOAD_MAX_LEN = 252`
- max transmitted `length = 254`
- `PGFSK_KEEPALIVE_PAYLOAD_LEN = 16U`
- `PGFSK_KEEPALIVE_SEQ = UINT16_MAX`
- `PGFSK_KEEPALIVE_LEN = PGFSK_PACKET_METADATA_LEN + PGFSK_KEEPALIVE_PAYLOAD_LEN`
- keepalive `length = PGFSK_KEEPALIVE_LEN`
- payload packets never use `PGFSK_KEEPALIVE_SEQ`
- zero-length app TX frames are invalid

## Buffers

`radio_hw.c` owns the packet buffers:

```c
g_tx_ring[PGFSK_HW_TX_RING_DEPTH]
g_rx_ring[PGFSK_HW_RX_RING_DEPTH]
g_keepalive_packet
```

Ring ownership:

| Ring index | Writer |
|---|---|
| TX write | link thread |
| TX read | radio ISR |
| RX write | radio ISR |
| RX read | link thread |

Rings are SPSC. One slot remains unused to distinguish full from empty.

TX ring rules:

- TX ring contains payload packets only.
- Keepalives are never queued in the TX ring.
- Link publishes a payload by filling `pgfsk_hw_tx_get_wr_ptr()` and then
  calling `pgfsk_hw_tx_advance_wr_idx()`.
- Link-thread publication does not touch `PACKETPTR`.

RX ring rules:

- RADIO DMA writes to `g_rx_ring[g_rx_wr_idx]`.
- `CRCOK`/`CRCERROR` queues a metadata-only event.
- RX write index advances only if the RX ring has room and event queueing
  succeeds.
- Link releases a consumed RX slot with `pgfsk_hw_rx_advance_rd_idx()`.

## RADIO Shortcuts

Base shorts:

- `READY_START`
- `PHYEND_DISABLE`
- `ADDRESS_RSSISTART`

Turn-selection shorts:

- `DISABLED_RXEN`
- `DISABLED_TXEN`

The active shortcut set is:

- RX path: `BASE | DISABLED_RXEN`
- TX path: `BASE | DISABLED_TXEN`

## PACKETPTR Rules

RX programming:

```text
PACKETPTR = &g_rx_ring[g_rx_wr_idx]
```

TX programming:

```text
PACKETPTR = &g_tx_ring[g_tx_rd_idx] if TX ring non-empty
PACKETPTR = &g_keepalive_packet     if TX ring empty
```

Programming points:

| Point | Action |
|---|---|
| `pgfsk_hw_start()` | Program initial RX pointer. |
| `ADDRESS` while `LISTEN` | Program next TX pointer. |
| `LISTEN`/`IN_RX` timeout | Program TX pointer directly before switchover to TX. |
| `ADDRESS` while `IN_TX` | Program next RX pointer. |

## Deadlines

Timer:

- TIMER10 runs at 1 MHz.
- CC[2] captures `ADDRESS`.
- CC[3] is the semantic deadline compare.
- CC[4] captures `PHYEND`.

Deadline rules:

| Entry | Deadline |
|---|---|
| start -> `LISTEN` | `now + BASE_US + jitter` |
| `ADDRESS` -> `IN_RX` | `address_tick + MAX_PACKET_AIRTIME_US` |
| TX `PHYEND` -> `LISTEN` | `tx_phyend_tick + MAX_PACKET_AIRTIME_US + jitter` |

`radio_hw` clamps too-late deadlines forward by
`PGFSK_HW_DEADLINE_MIN_LEAD_US` and increments `deadline_late_count`.

TX ring publication never changes deadlines.

## State Transitions

### `LISTEN -> IN_RX`

Trigger: RADIO `ADDRESS`.

Actions:

- set `turn_state = IN_RX`
- arm RX deadline
- program TX `PACKETPTR` to TX ring head or keepalive
- set shorts to `BASE | DISABLED_TXEN`

### `LISTEN -> IN_TX`

Trigger: listen timeout deadline.

Actions:

- queue `LISTEN_TIMEOUT`
- program TX `PACKETPTR` to TX ring head or keepalive
- clear pending `ADDRESS`
- set `turn_state = IN_TX`
- trigger RADIO `DISABLE`
- if trigger fails, queue `TX_TRIGGER_FAILED`

### `IN_RX -> IN_TX`

Triggers:

- RX `PHYEND`, after `CRCOK`/`CRCERROR`
- RX timeout deadline

RX `PHYEND` actions:

- `CRCOK` queues `RX_OK`; `CRCERROR` queues `RX_BAD`
- RX write index advances if event queueing succeeds
- `PHYEND` handler sets `turn_state = IN_TX`
- hardware short starts TX

RX timeout deadline actions:

- queue `RX_INCOMPLETE`
- program TX pointer
- set `turn_state = IN_TX`
- trigger RADIO `DISABLE`

### `IN_TX -> LISTEN`

Trigger: TX `PHYEND`.

Actions:

- advance TX read index only if the transmitted packet came from TX ring buffer
- set `turn_state = LISTEN`
- arm post-TX listen deadline
- increment TX stats
- queue `TX_END`

`TX_END` is queued from `PHYEND`, not from `DISABLED`. The next RX pointer was
already programmed by TX `ADDRESS`.

## Link Handling

`RX_OK`:

- read RX packet from RX ring
- reject malformed length and release slot
- reset `consecutive_rx_misses`
- enter `IN_SERVICE`
- if keepalive marker: no app frame, no seq accounting
- if payload: queue app RX frame and update seq/loss accounting
- release RX slot

`RX_BAD`:

- reset `consecutive_rx_misses`
- release RX slot
- do not enter service from `NO_SERVICE`

`RX_INCOMPLETE`:

- increment `rx_incomplete_count`
- reset `consecutive_rx_misses`

`LISTEN_TIMEOUT`:

- if `IN_SERVICE`, increment `consecutive_rx_misses`
- if threshold reached, mark `NO_SERVICE`
- if already `NO_SERVICE`, log rate-limited waiting warning

`TX_END`:

- refill TX ring with queued payloads until full or app TX queue empty

`TX_TRIGGER_FAILED`:

- increment `tx_trigger_fail_count`
- mark `NO_SERVICE`
- log error
- stop radio path

## Service State

External states:

- `NO_SERVICE`
- `IN_SERVICE`

Enter service:

- valid `RX_OK` packet, including keepalive

Stay in service:

- `RX_OK`, `RX_BAD`, and `RX_INCOMPLETE` all reset misses

Leave service:

- only consecutive `LISTEN_TIMEOUT` events count as missed peer activity
- threshold is `PGFSK_LINK_SYNC_LOSS_TURNS`

On service loss:

- increment outage counter if previously in service
- reset miss counter
- clear in-service timestamp
- clear RX sequence continuity
- do not reset hardware turn state

## Responsibilities

`radio_hw` owns:

- RADIO/TIMER configuration
- turn state
- deadlines and jitter
- `PACKETPTR` and shorts
- RX/TX rings
- keepalive fallback packet
- metadata-only hardware event queue
- hardware stats

`link.c` owns:

- service state
- app TX/RX queues
- payload copy into TX ring
- payload sequence/loss accounting
- keepalive RX policy
- user-visible link stats/logs

## Invariants

1. Both roles use identical timing logic.
2. `PHYEND` anchors packet end.
3. `ADDRESS` is the only peer packet start gate.
4. `FRAMESTART` and `SYNC` are not protocol inputs.
5. `link.c` does not own hardware turn state.
6. RX events do not carry packet payloads.
7. TX ring entries are payload-only.
8. Empty TX ring means transmit `g_keepalive_packet`.
9. Keepalive does not consume payload sequence numbers.
10. Payload sequence generation skips `PGFSK_KEEPALIVE_SEQ`.
11. Link-thread TX publication does not program `PACKETPTR`.
12. Listen timeout is a hard turn boundary.
13. Stop purges stale hardware events and leaves hardware state disabled.

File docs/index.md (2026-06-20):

# FlexAudioLink Documentation

- [Getting Started](getting-started.md) — toolchain setup, build, and flash instructions
- [Firmware](firmware/index.md) — firmware architecture, audio path, radio timing, and latency measurements
- [Hardware](hardware.md) — schematic, PCB, rationale for chosen components
- [Web UI](webui.md) — setup and configuration
- [CLI Reference](cli.md) — available CLI commands

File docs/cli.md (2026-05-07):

# CLI Reference

The nRF firmware exposes a USB CDC CLI in `firmware/src/cli.c`.

## Commands

| Command | Description |
|---|---|
| `help` | Show available commands |
| `get` | Get current configuration |
| `set mode <usb\|prop_dongle\|prop_headset>` | Set the boot mode |
| `status` | Show device status |
| `status on [ms]` | Enable periodic status output with optional interval |
| `status off` | Disable periodic status output |
| `scan` | Run a BLE/prop scan |
| `linktest on\|off\|status` | Control link test mode |
| `i2s tone on\|off\|status` | Control I2S tone generator |
| `reset` | Reset the device |

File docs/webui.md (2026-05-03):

# Web UI

The `webui/` directory contains:

- a **Svelte application** in `webui/app/`
- a **Python WebSocket-to-serial bridge** in `webui/websocket_serial_bridge.py`

## Communication

The UI communicates with the device over USB CDC ACM using:

- **WebSerial** in Chromium-based browsers
- a local **WebSocket bridge** for browsers without WebSerial support

!!! warning
    `webui/spec.md` is broader than the currently implemented firmware surface and should be read as intent rather than as a statement of completed firmware behavior.

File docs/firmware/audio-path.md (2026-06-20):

# Audio Path

Audio path code owns the PCM routing selected by `app_control` at boot. PROP is
treated as a packet service here; radio/TDD internals are covered in
[PROP TDD](prop-tdd.md), and codec-facing PCM transport is covered in
[I2S/TDM](i2s-tdm.md).

## Source Files

| File | Ownership |
|---|---|
| `firmware/src/app_control.c` | Selects the boot mode and initializes the matching path. |
| `firmware/src/audio/path_common.*` | Shared path state names, level filter, PI controller, global fixed/auto FLL state, and PROP audio packet-size symbols. |
| `firmware/src/audio/path_wired.c` | Direct USB audio to codec path. |
| `firmware/src/audio/path_dongle.c` | USB audio to PROP path for the dongle. |
| `firmware/src/audio/path_headset.c` | PROP audio to codec path for the headset. |
| `firmware/src/usb/usb_audio.*` | TinyUSB audio FIFO adapter and audio reset helper. |
| `firmware/src/audio/i2s.*` | I2S/TDM activation API and codec-facing transport thread. |

## Path Matrix

| Mode | Path | Speaker flow | Mic flow | Buffer/FLL |
|---|---|---|---|---|
| `usb` | `path_wired` | USB EP OUT FIFO -> I2S TX | I2S RX left mono -> USB EP IN FIFO | Uses `BUFFERING` / `PLAYING` and FLL PI control. |
| `prop_dongle` | `path_dongle` | USB EP OUT FIFO -> PROP TX queue | PROP RX queue -> USB EP IN FIFO | No I2S, codec, buffering state, or FLL control. |
| `prop_headset` | `path_headset` | PROP RX queue -> speaker FIFO -> I2S TX | I2S RX left mono -> mic FIFO -> PROP TX queue | Uses `BUFFERING` / `PLAYING` and FLL PI control. |

The active path is derived from the persisted `app_control` mode. The CLI
`set mode <usb|prop_dongle|prop_headset>` command saves the new mode and
reboots; paths are not hot-swapped without reboot.

## Audio Units

The fixed PCM geometry lives in `firmware/src/audio/audio_config.h`.
Speaker audio is 48 kHz, 16-bit, stereo PCM; microphone audio is 48 kHz,
16-bit, mono PCM after the I2S layer extracts the left channel.

Important derived units:

| Symbol | Meaning |
|---|---|
| `AUDIO_SPK_TARGET_BYTES` | Target speaker buffer level used to start I2S-backed paths and close the FLL loop. |
| `AUDIO_SPK_BUFFER_BYTES` | Local headset speaker FIFO capacity. |
| `AUDIO_MIC_BUFFER_BYTES` | Local headset mic FIFO capacity. |
| `AUDIO_I2S_BLOCK_BYTES` | I2S DMA block size and speaker transfer unit. |
| `PROP_SPK_PACKET_BYTES` | One PROP speaker payload. |
| `PROP_MIC_PACKET_BYTES` | One PROP mic payload. |

## Buffer States

Buffer states are only used by the I2S-backed paths: `path_wired` and
`path_headset`. `path_dongle` does not maintain `BUFFERING` / `PLAYING`; it
moves USB and PROP payloads whenever complete payloads are available.

| State | Meaning |
|---|---|
| `PATH_STATE_BUFFERING` | Path is waiting for enough speaker data before activating I2S. |
| `PATH_STATE_PLAYING` | Path has activated I2S and is feeding speaker blocks. |

Wired and headset paths use the same state rule shape: start playback when the
speaker FIFO plus pending I2S bytes reaches `AUDIO_SPK_TARGET_BYTES`, and return
to buffering when pending I2S data has drained and the speaker FIFO has less
than one full `AUDIO_I2S_BLOCK_BYTES` block. Returning to buffering increments
`spk_underrun_events`.

## Runtime Behavior

`path_wired`:

- Waits for TinyUSB audio EP OUT and EP IN FIFOs.
- Uses the USB speaker FIFO directly as the I2S TX source.
- Starts I2S when USB speaker level plus I2S pending bytes reaches
  `AUDIO_SPK_TARGET_BYTES`.
- Stops I2S and increments `spk_underrun_events` when playback drains below one
  I2S block.
- Retunes the codec FLL while playing.

`path_dongle`:

- Waits for TinyUSB audio EP OUT and EP IN FIFOs.
- Reads USB speaker data in `PROP_SPK_PACKET_BYTES` chunks and enqueues PROP TX
  packets.
- Dequeues PROP RX packets with `PROP_MIC_PACKET_BYTES` payloads and writes them
  to the USB mic FIFO.
- Counts speaker bytes consumed from USB after a PROP TX enqueue failure in
  `overflow_bytes`.

`path_headset`:

- Creates local TinyUSB-style speaker and mic FIFOs with `tu_fifo_config()`.
- Moves PROP speaker packets into the local speaker FIFO.
- Starts I2S when speaker FIFO plus pending I2S bytes reaches
  `AUDIO_SPK_TARGET_BYTES`.
- Sends complete mic payloads from the local mic FIFO to PROP TX.
- Retunes the codec FLL while playing.

## PROP Audio Payloads

Audio paths enqueue and dequeue `struct prop_packet` objects through the PROP
session API. `prop_packet.length` includes `PROP_PACKET_METADATA_LEN`; audio
payload size is `packet.length - PROP_PACKET_METADATA_LEN`.

| Direction | Payload size |
|---|---|
| Dongle -> Headset speaker | `PROP_SPK_PACKET_BYTES` |
| Headset -> Dongle mic | `PROP_MIC_PACKET_BYTES` |

The audio payload does not carry a stream ID or duplicate byte count. Direction
is implied by the active device role.

## FLL Controller

The I2S-backed path threads monitor speaker level while playing and run the FLL
controller when automatic FLL mode is active:

| Input | Use |
|---|---|
| Path target | Desired total speaker level in bytes. |
| Software FIFO level | Current path-owned speaker FIFO level. |
| I2S pending level | Bytes submitted to the I2S pipeline and not yet matched by RX completion. |

Each path periodically filters `fifo + pending` with
`codec_level_filter_update()`. On the FLL update interval, it passes
`AUDIO_SPK_TARGET_BYTES` and `AUDIO_SAMPLE_RATE_HZ` to
`codec_clock_controller()`. The controller computes buffer error, derives
warning levels from the target, applies PI control, and calls
`nau88l21_set_fll_target_rate_hz()` with `AUDIO_SAMPLE_RATE_HZ - adjust_hz`.

`fll_set_fixed()` pauses automatic updates by setting a global fixed target;
`fll_set_auto()` resumes automatic control. FLL control is unavailable in
`prop_dongle` mode because that path does not use the codec or I2S.

## USB Audio Adapter

Audio paths read and write TinyUSB endpoint FIFOs directly:

| Direction | FIFO accessor |
|---|---|
| Speaker source | `tud_audio_get_ep_out_ff()` |
| Microphone sink | `tud_audio_get_ep_in_ff()` |

`usb_audio_reset()` restores nominal feedback and clears the audio endpoint
FIFOs. USB audio callbacks wake `path_wired` or `path_dongle` depending on the
current mode.

## CLI Status

`status_audio on [ms]` enables periodic `#A ...` lines. `status_audio off`
disables them.

`usb` and `prop_headset` report the shared codec path status:

- `state`
- `spk_fifo_bytes`
- `spk_pending_bytes`
- `spk_filtered_level_bytes`
- `spk_error_bytes`
- `spk_p_adjust_hz`
- `spk_i_adjust_hz`
- `spk_fll_target_rate_hz`
- `spk_underruns`

`prop_dongle` reports:

- `overflow_bytes`

## Constraints

- Audio format is fixed by compile-time constants; it is not negotiated per
  path.
- Speaker samples are stereo; captured I2S samples are reduced to mono by
  keeping the left channel in the I2S layer.
- The active path is selected at boot from persisted mode.
- PROP audio uses fixed speaker and mic packet sizes.
- Path modules do not implement packet-loss concealment.

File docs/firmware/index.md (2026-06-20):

# Firmware Overview

FlexAudioLink firmware is a Zephyr application for
`nrf54lm20dk/nrf54lm20a/cpuapp`. `main.c` only enters `app_control_boot()`;
long-running work is handled by subsystem threads such as USB, CLI, I2S, PROP,
and the active audio path.

## Module Map

| Module | Purpose | Source files |
|---|---|---|
| `app_control` | Loads persisted boot mode, starts the selected path, and gates USB startup. | `firmware/src/app_control.c`, `firmware/src/main.c` |
| Audio path | Mode-specific audio routing and buffer control. | `firmware/src/audio/path_common.*`, `path_wired.c`, `path_dongle.c`, `path_headset.c` |
| I2S/TDM | Codec-facing PCM transport thread and Zephyr I2S driver owner. | `firmware/src/audio/i2s.*` |
| NAU88L21 | I2C codec init, clock-master setup, headphone DAC bring-up, FLL retune API. | `firmware/src/audio/nau88l21.*` |
| TinyUSB device | USBHS startup, TinyUSB task loop, and mode-dependent descriptors for UAC+CDC or CDC-only enumeration. | `firmware/src/usb/usb_device.c`, `usb_descriptors.c`, `tusb_config.h` |
| USB audio | UAC endpoint FIFOs and UAC control requests. | `firmware/src/usb/usb_audio.c`, `usb_audio.h` |
| CDC CLI | USB CDC transport, command parser, and status emitter. | `firmware/src/usb/usb_cdc.c`, `firmware/src/cli.c` |
| PROP subsystem | Proprietary radio session queues and radio/TDD engine. Treat as one subsystem from audio code. | `firmware/src/prop/session.*`, `radio_core.*` |

See [PROP TDD](prop-tdd.md) for radio turn timing, packet ownership, and
`session.c` / `radio_core.c` coupling.

## Firmware References

- [Audio Path](audio-path.md) describes mode-specific routing, buffering, PROP
  audio payloads, FLL control, USB audio integration, and CLI audio status.
- [I2S/TDM](i2s-tdm.md) describes codec-facing PCM transport, DMA blocks,
  pending-byte accounting, and the nRF TDM configuration.
- [NAU88L21 Codec](nau88l21-codec.md) describes codec initialization, clock
  master setup, headphone output bring-up, and FLL retuning.
- [PROP TDD](prop-tdd.md) describes radio turn timing, packet ownership,
  queueing, and loss accounting.
- [Latency Measurement](latency_measurement.md) records the measured downstream
  firmware/device latency from dongle marker GPIO to headset analog output.

## Boot Modes

`app_control_boot()` initializes Zephyr settings, reads `mode/active`, defaults
to `usb`, and starts one route:

| Mode | Started modules | Audio route |
|---|---|---|
| `usb` | `path_wired_init()` | USB speaker -> I2S/TDM -> codec, codec RX -> USB mic |
| `prop_dongle` | `prop_session_start_dongle()`, `path_dongle_init()` | USB speaker -> PROP, PROP -> USB mic |
| `prop_headset` | `prop_session_start_headset()`, `path_headset_init()` | PROP -> I2S/TDM -> codec, codec RX -> PROP |

The USB device thread waits on `app_control_await_boot()` before TinyUSB
initialization. Mode changes are persisted by the CLI and require reboot.

## Runtime Ownership

| Owner | Runtime resources |
|---|---|
| `app_control` | Current mode enum and settings key `mode/active`. |
| Audio path threads | Route-local state, TinyUSB FIFO access, PROP session queue use, buffer/FLL status. |
| I2S thread | `tdm` device, TX/RX DMA slabs, I2S command queue, pending-byte counter. |
| NAU88L21 driver | `i2c23` device pointer after init and FLL fractional register writes. |
| USB device thread | USBHS low-level init, TinyUSB task loop, UAC/CDC descriptors. |
| CLI thread | Command queue, async output queue, periodic link/audio status output. |
| PROP subsystem | Radio packet rings, app-facing PROP queues, session status and loss accounting. |

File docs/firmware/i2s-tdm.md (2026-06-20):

# I2S/TDM

`firmware/src/audio/i2s.*` owns the Zephyr I2S/TDM device and presents a FIFO
based PCM transport to the audio path modules.

## Purpose

Move fixed-size PCM blocks between path-owned FIFO objects and the nRF TDM
peripheral.

## Source Files

| File | Role |
|---|---|
| `firmware/src/audio/i2s.c` | I2S thread, Zephyr I2S config, DMA slabs, active/inactive loop. |
| `firmware/src/audio/i2s.h` | I2S activation API; includes the shared PCM constants from `audio_config.h`. |
| `firmware/prj.conf` | Enables I2S and sets TX/RX TDM block counts. |
| `firmware/boards/nrf54lm20dk_nrf54lm20a_cpuapp.overlay` | TDM pins, DMA RAM region, 32 MHz reference clock output. |

## Buffers

| Direction | FIFO contract |
|---|---|
| Speaker TX | Reads complete stereo PCM blocks of `AUDIO_I2S_BLOCK_BYTES` from the path-provided TX FIFO. |
| Mic RX | Writes a mono chunk containing one left-channel sample per stereo frame to the path-provided RX FIFO. |

## Ownership

The I2S thread owns the `tdm` device, TX/RX DMA slabs, command queue, running
flag, and pending-byte counter. Audio path modules own the `tu_fifo_t` objects
passed into `audio_i2s_activate()`.

The FIFO type is always TinyUSB's `tu_fifo_t`, even when the active path is not
using USB audio. In headset mode, USB enumerates CDC-only, but `path_headset`
still defines local static speaker and mic FIFOs with `tu_fifo_config()`. This
lets wired and headset playback use the same I2S buffering contract: the I2S
layer only sees a TX FIFO and an RX FIFO, not whether those FIFOs are USB
endpoint FIFOs or local path buffers.

## PCM Geometry

| Symbol | Meaning |
|---|---|
| `AUDIO_SAMPLE_RATE_HZ` | Fixed PCM frame rate used by USB, I2S, PROP sizing, and codec FLL targeting. |
| `AUDIO_I2S_CHANNELS` | Number of TDM/I2S slots. |
| `AUDIO_BITS_PER_SAMPLE` | Bits per channel sample. |
| `AUDIO_I2S_BYTES_PER_FRAME` | Bytes per interleaved I2S stereo sample pair. |
| `AUDIO_I2S_BYTES_PER_MS` | Derived byte rate for stereo PCM. |
| `AUDIO_I2S_BLOCK_BYTES` | DMA block size and speaker FIFO transfer unit. |
| `AUDIO_I2S_SAMPLE_PAIRS_PER_BLOCK` | Interleaved L/R sample pairs per DMA block. |

## Stereo To Mono

The TDM/codec interface is configured as stereo, but the firmware exports mic
audio as mono. `audio_i2s_rx_block()` calls `extract_left_to_mono()` on every
RX block before writing to the path RX FIFO.

The extraction copies the left channel sample from each interleaved stereo
frame into the front of the same slab block, then writes the resulting mono
chunk to the RX FIFO. The right channel is ignored. Keeping this conversion in
the I2S layer means `path_wired` and `path_headset` both receive the same mono
mic FIFO format; neither path needs to understand the codec stereo slot layout.

## Public API

| Function | Behavior |
|---|---|
| `audio_i2s_activate(tx_fifo, rx_fifo)` | Enqueues an activate command with path-owned FIFOs. |
| `audio_i2s_deactivate()` | Enqueues a deactivate command. |
| `audio_i2s_tx_get_pending_bytes()` | Returns speaker bytes submitted to I2S and not yet matched by RX completion. |

The command queue depth is one. Calls block if the command slot is full.
Current implementation requires both `tx_fifo` and `rx_fifo` to be non-null.

## Thread Startup

`K_THREAD_DEFINE(audio_i2s_thread_id, ...)` starts the I2S thread at boot.

Startup sequence:

1. Verify `tdm` and `i2c23` devices are ready.
2. Initialize the NAU88L21 codec over I2C.
3. Configure Zephyr I2S TX and RX directions.
4. Wait for an activate command.

## Zephyr I2S Config

Both directions use:

| Field | Value |
|---|---|
| `word_size` | `AUDIO_BITS_PER_SAMPLE` |
| `channels` | `AUDIO_I2S_CHANNELS` |
| `format` | `I2S_FMT_DATA_FORMAT_I2S` |
| `frame_clk_freq` | `AUDIO_SAMPLE_RATE_HZ` |
| `block_size` | `AUDIO_I2S_BLOCK_BYTES` |
| `options` | `I2S_OPT_BIT_CLK_SLAVE \| I2S_OPT_FRAME_CLK_SLAVE` |

The I2S config `timeout` field differs by direction:

| Direction | Timeout |
|---|---|
| TX | `0` / no wait |
| RX | `SYS_FOREVER_MS` |

DMA memory comes from static slabs:

| Slab | Block size | Block count |
|---|---:|---:|
| TX | `AUDIO_I2S_BLOCK_BYTES` | `CONFIG_I2S_NRF_TDM_TX_BLOCK_COUNT` |
| RX | `AUDIO_I2S_BLOCK_BYTES` | `CONFIG_I2S_NRF_TDM_RX_BLOCK_COUNT` |

The board overlay reserves a `DMA_RAM` region for TDM and TWIM EasyDMA.

## Active Loop

On activation:

- Pre-fill TX by submitting every full `AUDIO_I2S_BLOCK_BYTES` block currently
  available.
- Trigger `I2S_TRIGGER_START` for both directions.
- Retry start in a bounded prepare/start loop.

While active:

- Check for a queued deactivate command.
- Block on `i2s_read()` for the next RX block.
- Decrement pending TX bytes by one block after RX completion.
- Extract left channel to mono and write it to the RX FIFO.
- Submit all complete `AUDIO_I2S_BLOCK_BYTES` blocks available from the TX FIFO.

On stop or error, the thread issues `I2S_TRIGGER_DROP`, clears the running flag,
and resets pending bytes to zero.

## Pending Byte Accounting

`audio_i2s_tx_pending_bytes` increments by `AUDIO_I2S_BLOCK_BYTES` after each
successful `i2s_write()`. It decrements by the same amount after each
successful `i2s_read()`.

Audio path code adds this value to the speaker FIFO count so buffer control
includes both software-buffered audio and audio already committed to DMA/I2S.

## Codec Clock Relationship

Only codec-master clocking is supported:

- nRF TDM is BCLK/LRCK slave.
- The board drives MCLKI to the NAU88L21 from nRF PCLK.
- NAU88L21 FLL output generates the codec master clocks.
- Audio paths retune the codec FLL, which changes the I2S consume rate.

See [NAU88L21 Codec](nau88l21-codec.md) for clock and FLL details.

## Constraints

- PCM geometry is fixed by compile-time audio constants.
- One active path at a time.
- RX and TX progress are treated as paired for pending-byte accounting.
- Microphone data exported by this layer is left-channel mono only.

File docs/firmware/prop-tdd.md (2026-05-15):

# PROP Time Division Duplex

PROP — proprietary 2.4 GHz FSK link layer. TDD half-duplex: both peers share one channel, alternating TX/RX. No fixed slot assignment; listen timeout with random jitter resolves contention. Idle peer transmits keepalive or queued payload on timeout.

Implementation reference: `firmware/src/prop/`

- `radio_core.c` — authoritative for radio timing and DMA ownership. Entirely Timer/[DPPI](https://docs.nordicsemi.com/bundle/ps_nrf54LM20A/page/dppi.html) and ISR based.
- `session.c` — authoritative for service state, app queues, payload sequencing, and loss accounting.

## Protocol

- Both peers run identical half-duplex ping-pong logic.
- No role-specific slot timing exists.
- Device waits for RX to be done then sends itself, then listens again.
- A TX turn always sends either one queued payload packet or one keepalive.
- Listen timeouts include random jitter; the first peer to time out transmits, breaking deadlock.

## Radio Turn State

<figure markdown>
  
  <figcaption>Radio turn state machine</figcaption>
</figure>

Active protocol states:

| State | Meaning |
|---|---|
| `LISTEN` | Radio waits for peer `ADDRESS` or listen deadline. |
| `IN_RX` | Peer packet has reached `ADDRESS`; RX deadline is armed. |
| `IN_TX` | Local TX has been committed; late peer `ADDRESS` is ignored. |

Implementation sentinel:

| State | Meaning |
|---|---|
| `DISABLED` | Radio path stopped; not a protocol turn. |

## RADIO Peripheral Events

Reference: [nRF RADIO peripheral docs](https://docs.nordicsemi.com/bundle/ps_nrf54LM20A/page/radio.html)

| Event | Meaning |
|---|---|
| `ADDRESS` | Address field sent or matched |
| `PHYEND` | Full packet (including CRC) transmitted or received |
| `CRCOK` | Received packet CRC matched |
| `CRCERROR` | Received packet CRC failed |

Handled inside `radio_isr`.

## Session Events

`radio_core` emits one ordered event stream to `session.c`.

```c
struct prop_session_event {
    enum prop_session_event_type type;
    uint32_t tick;
    int16_t rssi_dbm;
};
```

| Event | Tick | Notes |
|---|---|---|
| `RX_OK` | RX `PHYEND` | RSSI valid. |
| `RX_BAD` | RX `PHYEND` | RSSI valid. |
| `TX_END` | TX `PHYEND` | TX already ended. |
| `RX_INCOMPLETE` | deadline | RX packet did not finish in time. |
| `LISTEN_TIMEOUT` | deadline | No peer `ADDRESS` before deadline. |
| `TX_TRIGGER_FAILED` | deadline | Timeout TX could not be triggered. |

## Packet Format

```c
struct prop_packet {
    uint8_t  length;
    uint16_t seq;
    uint8_t  data[PROP_DATA_MAX_LEN];
} __packed __aligned(4);
```

- packets never use `seq = PROP_KEEPALIVE_SEQ = UINT16_MAX` unless they are keepalive packets.
- zero-length app TX frames are invalid

Constants:

| Constant | Value |
|---|---|
| `PROP_PACKET_METADATA_LEN` | 2 |
| `PROP_DATA_MAX_LEN` | 252 |
| `PROP_KEEPALIVE_DATA_LEN` | 16 |
| `PROP_KEEPALIVE_SEQ` | `UINT16_MAX` |

## Buffers

`radio_core.c` owns the packet buffers. `PACKETPTR` always points to the
current read/write slot in these rings. The RADIO peripheral DMA transfers
directly to/from the pointed-to ring entry.

```c
tx_ring[PROP_RADIO_TX_RING_DEPTH]
rx_ring[PROP_RADIO_RX_RING_DEPTH]
keepalive_packet
```

Ring ownership:

| Ring index | Writer |
|---|---|
| TX write | session thread |
| TX read | radio ISR |
| RX write | radio ISR |
| RX read | session thread |

Rings are Single Producer Single Consumer (SPSC). One slot remains unused to distinguish full from empty.

TX ring rules:

- TX ring contains payload packets only.
- Keepalives are never queued in the TX ring.
- Session gets a pointer to the next TX slot via `prop_radio_tx_get_wr_ptr()`,
  copies into it, then commits with `prop_radio_tx_advance_wr_idx()`.
- Session-thread does not touch `PACKETPTR`.

RX ring rules:

- RADIO DMA writes to `rx_ring[rx_wr_idx]`.
- `CRCOK`/`CRCERROR` queues a session event.
- RX write index advances only if the RX ring has room and event queueing succeeds.
- Session releases a consumed RX slot with `prop_radio_rx_advance_rd_idx()`.

## RADIO Shortcuts

Reference: [nRF RADIO peripheral docs → SHORTS register](https://docs.nordicsemi.com/bundle/ps_nrf54LM20A/page/radio.html#ariaid-title112)

Base shorts (always active):

- `READY_START` — READY → START: begin TX/RX as soon as ramp-up completes.
- `PHYEND_DISABLE` — PHYEND → DISABLE: shut down radio after every packet.
- `ADDRESS_RSSISTART` — ADDRESS → RSSISTART: sample signal strength on peer packet arrival.

Turn-selection shorts (one active at a time):

- `DISABLED_RXEN` — DISABLED → RXEN: after disable, ramp back into RX.
- `DISABLED_TXEN` — DISABLED → TXEN: after disable, ramp into TX.

`PHYEND_DISABLE` + a turn-selection short chains the whole turnaround in hardware:
packet ends → radio disables → radio re-enables in the next direction, no ISR needed.

The active shortcut set prepares the *next* direction:

- while receiving: `BASE | DISABLED_TXEN` (turnaround into TX)
- while transmitting: `BASE | DISABLED_RXEN` (turnaround into RX)

## PACKETPTR and Shortcut Programming

PACKETPTR and shortcuts are always set together. Programming an RX pointer selects `DISABLED_TXEN`, programming a TX pointer selects `DISABLED_RXEN`.

RX programming:

```text
PACKETPTR = &rx_ring[rx_wr_idx]
```

TX programming:

```text
PACKETPTR = &tx_ring[tx_rd_idx]   if TX ring non-empty
PACKETPTR = &keepalive_packet       if TX ring empty
```

Programming points:

| Point | Action |
|---|---|
| `prop_radio_start()` | Program initial RX pointer. |
| `ADDRESS` while `LISTEN` | Program next TX pointer. |
| `LISTEN`/`IN_RX` timeout | Program TX pointer directly before switchover to TX. |
| `ADDRESS` while `IN_TX` | Program next RX pointer. |

## Deadlines

Timer:

- TIMER10 runs at 1 MHz.
- CC[2] captures `ADDRESS`.
- CC[3] is the semantic deadline compare.
- CC[4] captures `PHYEND`.

Constants:

| Constant | Meaning |
|---|---|
| `PROP_RADIO_LISTEN_TIMEOUT_BASE_US` | Fixed listen window before timeout. |
| `PROP_RADIO_LISTEN_TIMEOUT_JITTER_US` | Max random offset added to listen timeout. Determined by xorshift PRNG seeded from device ID and cycle counter. |
| `PROP_RADIO_MAX_PACKET_AIRTIME_US` | Worst-case packet duration on air. |
| `PROP_RADIO_DEADLINE_MIN_LEAD_US` | Minimum time a deadline must be in the future. |

Deadline rules:

| Entry | Deadline |
|---|---|
| start → `LISTEN` | `now + BASE_US + jitter` |
| `ADDRESS` → `IN_RX` | `address_tick + MAX_PACKET_AIRTIME_US` |
| TX `PHYEND` → `LISTEN` | `tx_phyend_tick + MAX_PACKET_AIRTIME_US + jitter` |

If a deadline is too close, `radio_core` clamps it forward by
`DEADLINE_MIN_LEAD_US` and increments `deadline_late_count`.

TX ring publication never changes deadlines.

## State Transitions

### `LISTEN` → `IN_RX`

Trigger: RADIO `ADDRESS`.

Actions:

- set `turn_state = IN_RX`
- arm RX deadline
- program TX `PACKETPTR` to TX ring head or keepalive

### `LISTEN` → `IN_TX`

Trigger: listen timeout deadline.

Actions:

- queue `LISTEN_TIMEOUT`
- program TX `PACKETPTR` to TX ring head or keepalive
- set shorts to `DISABLED_TXEN`
- clear pending `ADDRESS`, RX ADDRESS could arrive between timeout and `DISABLE`
- set `turn_state = IN_TX`
- trigger RADIO `DISABLE`
- if trigger fails, queue `TX_TRIGGER_FAILED`

### `IN_RX` → `IN_TX`

Triggers:

- RX `PHYEND`, after `CRCOK`/`CRCERROR`
- RX timeout deadline

RX `PHYEND` actions:

- `CRCOK` queues `RX_OK`; `CRCERROR` queues `RX_BAD`
- RX write index advances if event queueing succeeds
- `PHYEND` handler sets `turn_state = IN_TX`
- hardware short starts TX

RX timeout deadline actions:

- queue `RX_INCOMPLETE`
- program TX `PACKETPTR` to TX ring head or keepalive
- set shorts to `DISABLED_TXEN`
- clear pending `ADDRESS`, RX ADDRESS could arrive between timeout and `DISABLE`
- set `turn_state = IN_TX`
- trigger RADIO `DISABLE`
- if trigger fails, queue `TX_TRIGGER_FAILED`

### `IN_TX` → `LISTEN`

Trigger: TX `PHYEND`.

Actions:

- advance TX read index only if the transmitted packet came from TX ring buffer
- set `turn_state = LISTEN`
- arm post-TX listen deadline
- increment TX stats
- queue `TX_END`

`TX_END` is queued from `PHYEND`, not from `DISABLED`. The next RX pointer was
already programmed by TX `ADDRESS`.

## Session Handling

`RX_OK`:

- read RX packet from RX ring
- reject malformed length and advance RX read index (early return)
- reset `consecutive_rx_misses`
- enter `IN_SERVICE`
- if keepalive marker: no app frame, no seq accounting
- if payload: queue app RX frame and update seq/loss accounting
- advance RX read index

`RX_BAD`:

- reset `consecutive_rx_misses`
- advance RX ring buffer read index
- do not enter service from `NO_SERVICE`

`RX_INCOMPLETE`:

- increment `rx_incomplete_count`
- reset `consecutive_rx_misses`

`LISTEN_TIMEOUT`:

- if `IN_SERVICE`, increment `consecutive_rx_misses`
- if threshold reached, mark `NO_SERVICE`
- if already `NO_SERVICE`, log rate-limited waiting warning

`TX_END`:

- refill TX ring with queued payloads until full or app TX queue empty

`TX_TRIGGER_FAILED`:

- increment `tx_trigger_fail_count`
- mark `NO_SERVICE`
- log error
- stop radio path

## Service State

States:

- `NO_SERVICE`
- `IN_SERVICE`

Enter service:

- valid `RX_OK` packet, including keepalive

Stay in service:

- `RX_OK`, `RX_BAD`, and `RX_INCOMPLETE` all reset misses
- `RX_BAD` and `RX_INCOMPLETE` reset misses but do not enter service on their own

Leave service:

- only consecutive `LISTEN_TIMEOUT` events count as missed peer activity
- threshold is `PROP_SESSION_SYNC_LOSS_TURNS`

On service loss:

- increment outage counter if previously in service
- reset miss counter
- clear in-service timestamp
- clear RX sequence continuity
- do not reset radio turn state

## Responsibilities

`radio_core` owns:

- RADIO/TIMER configuration
- turn state
- deadlines and jitter
- `PACKETPTR` and shorts
- RX/TX rings
- keepalive fallback packet
- session event queue
- hardware stats

`session.c` owns:

- service state
- app TX/RX queues
- payload copy into TX ring
- payload sequence/loss accounting
- user-visible session stats/logs

## Invariants

1. Both roles use identical timing logic.
2. `PHYEND` anchors packet end.
3. `ADDRESS` is the only peer packet start gate.
4. `FRAMESTART` and `SYNC` are not protocol inputs.
5. `session.c` does not own radio turn state.
6. Session events do not carry packet payloads.
7. TX ring entries are payload-only.
8. Empty TX ring means transmit `keepalive_packet`.
9. Keepalive does not consume payload sequence numbers.
10. Payload sequence generation skips `PROP_KEEPALIVE_SEQ`.
11. Session-thread TX publication does not program `PACKETPTR`.
12. `PACKETPTR` and turn-selection shortcut are always programmed together.
13. `ADDRESS` must program the next-direction `PACKETPTR` before `PHYEND` fires.
14. Only `RX_OK` can enter service; `RX_BAD` and `RX_INCOMPLETE` cannot.
15. Listen timeout is a hard turn boundary.
16. Stop purges stale session events and leaves radio state disabled.

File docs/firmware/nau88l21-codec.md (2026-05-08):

# NAU88L21 Codec

`firmware/src/audio/nau88l21.*` owns NAU88L21 register programming and the
runtime FLL retuning API used by the I2S-backed audio paths.

## Purpose

Configure the codec as the I2S clock master, program the playback-related DAC
and headphone driver registers, and expose runtime sample-rate retuning through
the codec FLL.

## Source Files

| File | Role |
|---|---|
| `firmware/src/audio/nau88l21.c` | Register writes, FLL math, init sequence, runtime retune. |
| `firmware/src/audio/nau88l21.h` | Public init and retune API. |
| `firmware/src/audio/i2s.c` | Calls `nau88l21_init()` before I2S configuration. |
| `firmware/boards/nrf54lm20dk_nrf54lm20a_cpuapp.overlay` | I2C bus, TDM pins, 32 MHz MCLKI source. |

## Bus and Addressing

| Item | Value |
|---|---|
| I2C bus | `i2c23` |
| I2C address | `0x1B` |
| SDA / SCL | P3.11 / P3.12 |
| I2C speed | `I2C_BITRATE_STANDARD` |
| DMA region | `DMA_RAM` from the board overlay |

## Public API

| Function | Behavior |
|---|---|
| `nau88l21_init(i2c_dev)` | Uses the ready `i2c23` device to configure codec clocking and playback-related registers. |
| `nau88l21_set_fll_target_rate_hz(target_rate_hz)` | Validates a target near the firmware audio rate and updates the FLL fractional registers. |

Registers and values are private to `nau88l21.c`; the driver does not expose a
generic codec register access API.

## Ownership

The driver stores the initialized I2C device pointer for later retunes. The I2S
thread performs initialization; audio paths request retunes through
`path_common` helpers.

## Clocking

| Signal | Owner |
|---|---|
| 32 MHz MCLKI | nRF TDM MCK pin driven from PCLK on P1.10. |
| BCLK / LRCK | NAU88L21 codec master. |
| TDM SDOUT / SDIN | nRF TDM data pins. |

The nRF TDM driver is configured as bit-clock and frame-clock slave. The
NAU88L21 FLL is driven from the nRF-provided 32 MHz reference, then the codec
generates the I2S clocks used by the TDM peripheral. Exact divider values,
fractional FLL values, and derived clock rates live in `nau88l21.c`.

The driver has a build assertion for `NAU88L21_I2S_CODEC_CLOCK_MASTER`.

## Init Sequence

`nau88l21_init()`:

1. Stores the I2C device pointer for later retunes.
2. Writes reset register `0x00`.
3. Programs standard I2S for the firmware audio format.
4. Keeps SYSCLK on MCLK while programming the FLL.
5. Programs FLL ratio, integer, prescale, and fractional registers.
6. Writes FLL fractional registers before FLL5/FLL6 so the divider latches
   correctly.
7. Waits for the FLL path to settle, switches SYSCLK to the FLL path, and polls
   FLL lock.
8. Programs codec-master I2S clocks.
9. Runs static DAC/headphone output-path initialization.
10. Runs staged headphone output bring-up.

FLL lock failure is logged as a warning; init continues if I2C transactions
succeed.

## DAC / Headphone Bring-Up

The output path is intentionally staged:

| Stage | Action |
|---|---|
| Static init | Bias, left time slot, boost, Class G timer, analog control, DAC, charge pump, and HP ungrounding. |
| 0 | Enable Class G headphone amps. |
| 1 | Enable charge pump, wait for it to settle, then set playback charge-pump state. |
| 2 | Enable analog DACL/R. |
| 3 | Enable analog DAC clocks. |
| 4-6 | Enable output driver integrators, input stages, and main drivers. |
| 9 | Enable HP boost, Class G playback, and clear DAC test-bias gating. |
| Final | Enable DAC output stage and digital DACL/R, then wait for the output path to settle. |

## Runtime FLL Retuning

`nau88l21_set_fll_target_rate_hz()` retunes by writing FLL7/FLL8 only.

| Check | Behavior |
|---|---|
| Driver not initialized | Returns `-ENODEV`. |
| Target outside the supported retune window | Returns `-EINVAL`. |
| Computed FDCO outside the supported codec range | Returns `-ERANGE`. |
| Valid target | Computes the FLL fractional value and writes FLL7/FLL8. |

Audio paths call this through `path_common` helpers:

| Helper | Behavior |
|---|---|
| `fll_set_fixed(rate_hz)` | Applies a fixed target and pauses automatic path updates. |
| `fll_set_auto()` | Clears fixed mode; path PI control resumes. |
| `fll_get_fixed_rate()` | Returns fixed rate or zero for auto mode. |

## Constraints

- Only codec-master I2S clocking is supported.
- Register programming is fixed for the firmware audio format.
- Runtime retuning is limited to the narrow window enforced by `nau88l21.c`.
- The driver does not expose generic register read/write APIs.

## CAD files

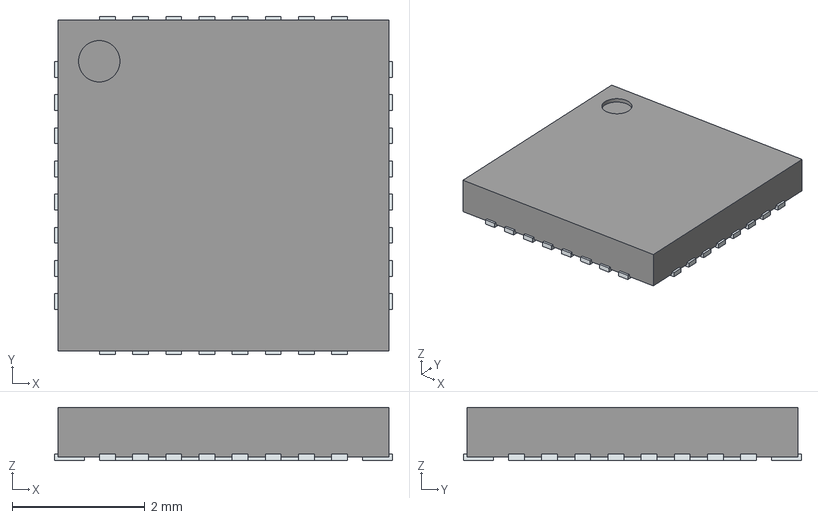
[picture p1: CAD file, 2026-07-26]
hardware/3D/NAU88L21YG.stp
5.10 x 5.10 x 0.8 mm
ThermalPin
PinsArrayLR
PinsArrayTB

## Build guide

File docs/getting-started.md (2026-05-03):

# Getting Started

## Prerequisites

Install host packages on Arch / EndeavourOS:

```bash
sudo pacman -S cmake ninja dtc gperf
yay -S python-west nrfutil
```

## Install the nRF Connect SDK

1. Clone the SDK source tree:

```bash
mkdir -p ~/ncs
cd ~/ncs
west init -m https://github.com/nrfconnect/sdk-nrf --mr v3.2.4 v3.2.4
cd ~/ncs/v3.2.4
west update
west zephyr-export
```

2. Install the matching Nordic-managed toolchain:

```bash
nrfutil install sdk-manager          # once
nrfutil sdk-manager install v3.2.4   # once per SDK version
```

3. Export `ZEPHYR_BASE`:

For `bash` / POSIX shells:

```bash
export ZEPHYR_BASE=~/ncs/v3.2.4/zephyr
```

Persistent in `fish`:

```fish
set -Ux ZEPHYR_BASE $HOME/ncs/v3.2.4/zephyr
```

Persistent in `bash`:

```bash
# ~/.bashrc
export ZEPHYR_BASE="$HOME/ncs/v3.2.4/zephyr"
```

## Clone and Build

Clone the repo and fetch the TinyUSB submodule:

```bash
cd ~
git clone https://github.com/gab-k/FlexAudioLink.git
cd ~/FlexAudioLink
git submodule update --init --recursive firmware/tinyusb
```

Launch a shell with the Nordic toolchain:

```bash
nrfutil sdk-manager toolchain launch --ncs-version v3.2.4 --shell
```

Build:

```bash
cd ~/FlexAudioLink/firmware
west build -b nrf54lm20dk/nrf54lm20a/cpuapp . --build-dir build
```

Pristine build:

```bash
cd ~/FlexAudioLink/firmware
west build -p always -b nrf54lm20dk/nrf54lm20a/cpuapp . --build-dir build
```

## VS Code Tasks

`tasks.json` provides:

- `west: build`
- `west: pristine build`

The VS Code tasks launch `west` through `nrfutil sdk-manager toolchain launch`, so they do not need hard-coded SDK bundle paths.

## Flash and Debug

The nrf54lm20dk eval board has an onboard Segger J-Link debugger. Flashing and debugging are done through VS Code using the Cortex-Debug extension with J-Link.

### Prerequisites

- Segger J-Link software installed on the host
- [Cortex-Debug](https://marketplace.visualstudio.com/items?itemName=marus25.cortex-debug) VS Code extension

### Flashing

The `launch.json` configurations build and flash in one step. Select the configuration matching your board's serial number (replace the serial number in `launch.json` with your own) and start debugging:

- `Debug (1051811555)` — board 1
- `Debug (1051890941)` — board 2

Both configurations:

- Build the firmware first (`preLaunchTask: west: build`)
- Flash via J-Link SWD to the `NRF54LM20A_M33` core
- Break at `main` on entry
- Enable RTT output

To flash without debugging:

```bash
nrfutil device program --firmware build/firmware/zephyr/zephyr.elf --traits nrf54lm20dk
```

Or via J-Link CLI:

```bash
JLinkExe -device NRF54LM20A_M33 -if SWD -speed 4000 -AutoErase
J-Link> loadfile build/firmware/zephyr/zephyr.elf
J-Link> r
J-Link> g
J-Link> exit
```

## Serial Console

Firmware log output (`printk` / `LOG_*`) goes to UART. Use any serial terminal at 115200 baud, or:

```bash
python python/q_term.py
```

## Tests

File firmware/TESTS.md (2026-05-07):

# nRF Firmware Test Plan

1. CI build
   Requirement:
   Build `nrf54lm20dk_debug` on every push and PR.
   Purpose:
   Fast regression gate for compile, link, and config changes.

2. USB CDC CLI smoke test
   Interface:
   USB CDC
   Minimum coverage:
   `help`, `get`, `status`, `set mode`, `scan`, `linktest`, `reset`, `i2s tone`
   Pass criteria:
   Device enumerates, accepts commands, returns sane status, and rejects invalid modes.

3. Two-board proprietary radio smoke test
   Setup:
   2 boards, one forced `dongle`, one forced `headset`
   Interface:
   CLI plus `linktest`
   Pass criteria:
   PROP session starts, headset reaches running state, lock is acquired within timeout, RX counters increase, RSSI is plausible, and rebooting into a different mode recovers cleanly.

4. USB descriptor enumeration stability
   Coverage:
   UAC+CDC descriptor set after booting `usb` and `prop_dongle`; CDC-only descriptor set after booting `prop_headset`.
   Pass criteria:
   Device enumerates with the mode-appropriate descriptors and retains functional CDC CLI after rebooting into each mode.

5. Soak test
   Duration:
   Long-run manual or scripted board test
   Pass criteria:
   No stalls, deadlocks, watchdog resets, counter corruption, or stuck mode reboot transitions.

## Lower Priority

6. Unit tests for isolated logic
   Only add these where there is a clean seam and a real payoff.
   Likely targets:
   mode validation, status formatting, packet bookkeeping

7. Failure injection
   Only add after a real failure mode is observed.
   Likely targets:
   mode persistence errors, radio start errors, codec init failures, I2S trigger or write failures

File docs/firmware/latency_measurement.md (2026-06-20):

# Latency Measurement

Measurement used to characterize the device latency of the PROP audio
path. The measured path starts when the dongle firmware recognizes a marker in a
USB speaker packet and ends when the corresponding marker appears at the headset
codec analog output.

## Measurement Principle

USB host plays a 48 kHz, stereo, signed 16-bit PCM WAV containing full-scale marker samples.

On the dongle, `path_dongle.c` scans each `PROP_SPK_PACKET_BYTES` speaker chunk
after it has been read from TinyUSB's EP OUT FIFO. When the marker pattern is
found, the dongle toggles GPIO P0.02. This GPIO edge is the measurement start
time.

The same marker samples are then transmitted to the headset over PROP and played
through the codec. The resulting analog pulse at the codec output is the
measurement stop time. The oscilloscope measures the time delta between the
dongle GPIO edge and the analog output pulse.

## Marker Format

Marker stimulus:

```text
Sample rate: 48 kHz
Channels:    2
Format:      signed 16-bit little-endian PCM
File:        python/latency_marker_48k_stereo.wav
Generator:   python/generate_latency_marker_wav.py
```

Marker sample sequence:

```text
+32767, +32767
-32768, -32768
+32767, +32767
-32768, -32768
```

The marker interval is aligned to the 1 ms speaker packet boundary. This keeps
the marker pattern inside a packet-sized chunk and allows deterministic marker
detection in `path_dongle.c`.

For the recorded measurement, the WAV was played from the USB host through a
direct ALSA hardware PCM device. This avoids host-side mixer gain, resampling,
or effects that could modify the full-scale marker samples.

## Measured Boundary

Measured interval:

```text
dongle P0.02 marker GPIO edge -> headset codec analog output pulse
```

The measured interval includes:

- dongle processing after the speaker packet has been read from TinyUSB EP OUT
- PROP TX enqueue and radio transfer
- headset PROP RX handling
- headset speaker FIFO buffering
- headset I2S scheduling and DMA
- codec output latency

## Probe Points

| Scope channel | Signal | Function |
|---|---|---|
| CH3 | Dongle P0.02 | Marker detection edge, measurement start |
| CH2 | Headset codec analog output | Reconstructed marker pulse, measurement stop |

P0.02 is used for the audio latency marker.

## Result

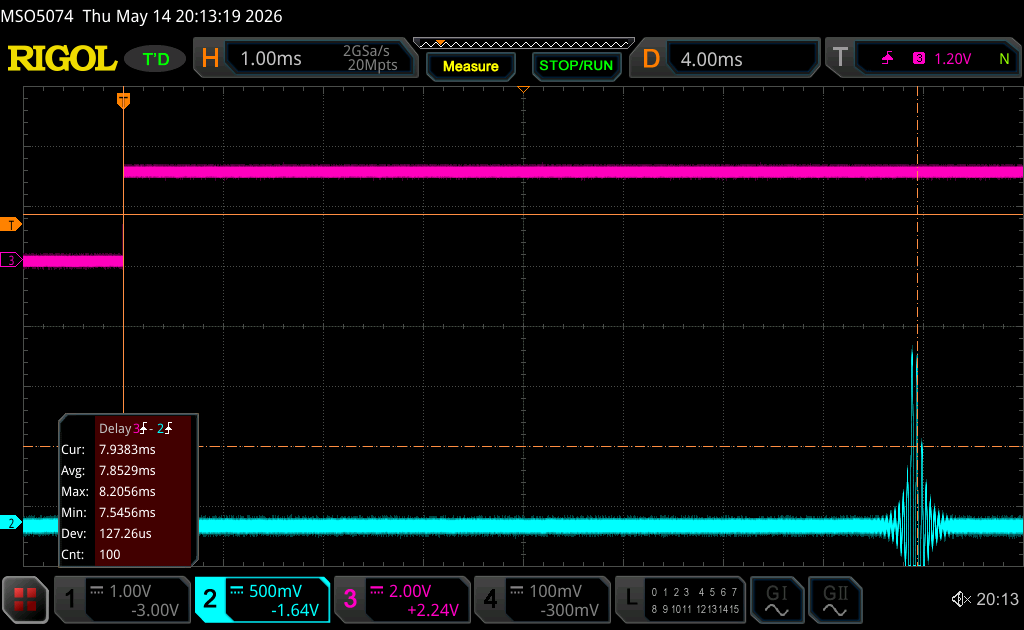
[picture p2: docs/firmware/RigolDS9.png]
Latency scope capture


Capture file:

```text
docs/RigolDS9.png
```

Oscilloscope measurement:

```text
Rigol Delta 3->2
CH3 marker edge to CH2 analog pulse
100 marker events
```

Recorded statistics:

| Statistic | Latency |
|---|---:|
| Average | 7.8529 ms |
| Minimum | 7.5456 ms |
| Maximum | 8.2056 ms |
| Standard deviation | 127.26 us |

## Limitations

The measured interval excludes:

- application/media-player latency on the USB host
- host OS audio stack latency
- USB host scheduling before the packet reaches dongle firmware
- time spent queued in TinyUSB's EP OUT FIFO before `path_dongle.c` drains it

This is therefore not an end-to-end PC playback latency measurement. It is a
device-path latency measurement referenced to the point where dongle firmware
has already consumed the USB speaker packet containing the marker.

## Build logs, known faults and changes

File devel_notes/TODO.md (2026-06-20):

# TODO

- Measure current consumption
- Measure USB Latency
- Explain buffers for each mode in docs

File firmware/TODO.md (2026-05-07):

# TODO

Documented here for later follow-up from review feedback on the recent PROP/CLI refactor.

## High Priority

### 1. Web UI mode command parsing not updated

- File: `src/cli.c`
- Problem: the firmware CLI now uses `set mode <usb|prop_dongle|prop_headset>` and returns `OK mode=...`.
- Impact: the Web UI may still send separate `role` / `mode` commands and track acknowledgements by those old parameter names.
- Fix direction: update the Web UI protocol/parser to use the single mode command.

## Medium Priority

### 2. `#S` status lines no longer expose `conn=`

- File: `src/cli.c`
- Problem: periodic `#S` status output replaced `conn=` with `lock=` / `state=`.
- Impact: the current Web UI parser only updates connection state from `conn=`, so the dashboard connection indicator no longer reflects the real device link state.
- Fix direction: either preserve `conn=` in firmware status pushes, or update the Web UI parser to understand the new fields.

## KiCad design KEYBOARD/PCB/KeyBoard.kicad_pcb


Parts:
A1: RaspberryPi_Pico; RaspberryPi_Pico_Common_Unspecified
D1, D2, D3, D4, D5, D6, D7, D8, D9, D10, D11, D12, D13, D14, D15, D16, D17, D18, D19, D20, D21, D22, D23, D24, D25, D26, D27, D28, D29, D30, D31, D32, D33, D34, D35, D36, D37, D38, D39, D40, D41, D42, D43, D44, D45, D46, D47, D48, D49, D50, D51, D52, D53, D54, D55, D56, D57, D58, D59, D60, D61: 1N4148; D_DO-35_SOD27_P7.62mm_Horizontal
S1: MX_stab; STAB_MX_2u
S2, S3: MX_stab; STAB_MX_2.25u
S4: MX_stab; STAB_MX_2.75u
S5: MX_stab; STAB_MX_6.25u
SW1, SW2, SW3, SW4, SW5, SW6, SW7, SW8, SW9, SW10, SW11, SW12, SW13, SW16, SW17, SW18, SW19, SW20, SW21, SW22, SW23, SW24, SW25, SW26, SW27, SW30, SW31, SW32, SW33, SW34, SW35, SW36, SW37, SW38, SW39, SW40, SW51, SW52, SW53, SW54, SW55, SW56, SW57, SW58, SW59, SW60: SW_Push; SW_Cherry_MX_1.00u_PCB
SW14: SW_Push; SW_Cherry_MX_2.00u_PCB
SW15: SW_Push; SW_Cherry_MX_1.50u_PCB
SW28: SW_Push; SW_Cherry_MX_1.50u_Plate
SW29: SW_Push; SW_Cherry_MX_1.75u_PCB
SW41, SW50: SW_Push; SW_Cherry_MX_2.25u_PCB
SW42, SW43, SW44, SW46, SW48, SW49: SW_Push; SW_Cherry_MX_1.25u_PCB
SW45: SW_Push; SW_Cherry_MX_6.25u_PCB
SW47: SW_Push; SW_Cherry_MX_1.25u_Plate
SW61: SW_Push; SW_Cherry_MX_2.75u_PCB
SW62, SW63: RotaryEncoder_Switch_MP; RotaryEncoder_Alps_EC11E-Switch_Vertical_H20mm

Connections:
A1: A1.27 (GPIO21), SW62.A
A2: A1.32 (GPIO27_ADC1), SW63.A
B1: A1.29 (GPIO22), SW62.B
B2: A1.34 (GPIO28_ADC2), SW63.B
C0: A1.10 (GPIO7), SW1.1, SW15.1, SW29.1, SW42.1, SW50.1
C1: A1.11 (GPIO8), SW2.1, SW16.1, SW30.1, SW43.1, SW51.1
C2: A1.12 (GPIO9), SW3.1, SW17.1, SW31.1, SW44.1, SW52.1
C3: A1.14 (GPIO10), SW4.1, SW18.1, SW32.1, SW53.1
C4: A1.15 (GPIO11), SW5.1, SW19.1, SW33.1, SW54.1
C5: A1.16 (GPIO12), SW6.1, SW20.1, SW34.1, SW45.1, SW55.1
C6: A1.17 (GPIO13), SW7.1, SW21.1, SW35.1, SW56.1
C7: A1.19 (GPIO14), SW8.1, SW22.1, SW36.1, SW57.1
C8: A1.20 (GPIO15), SW9.1, SW23.1, SW37.1, SW46.1, SW58.1
C9: A1.21 (GPIO16), SW10.1, SW24.1, SW38.1, SW47.1, SW59.1
C10: A1.22 (GPIO17), SW11.1, SW25.1, SW39.1, SW48.1, SW60.1
C11: A1.24 (GPIO18), SW12.1, SW26.1, SW40.1, SW49.1, SW61.1
C12: A1.25 (GPIO19), SW13.1, SW27.1, SW41.1
C13: A1.26 (GPIO20), SW14.1, SW28.1
GND: A1.33 (AGND), SW62.C, SW62.S2, SW63.C, SW63.S2
unnamed: A1.3 (GND), A1.8 (GND), A1.13 (GND), A1.18 (GND), A1.23 (GND), A1.28 (GND), A1.38 (GND)
unnamed: D1.2 (A), SW1.2
unnamed: D2.2 (A), SW2.2
unnamed: D3.2 (A), SW3.2
unnamed: D4.2 (A), SW4.2
unnamed: D5.2 (A), SW5.2
unnamed: D6.2 (A), SW6.2
unnamed: D7.2 (A), SW7.2
unnamed: D8.2 (A), SW8.2
unnamed: D9.2 (A), SW9.2
unnamed: D10.2 (A), SW10.2
unnamed: D11.2 (A), SW11.2
unnamed: D12.2 (A), SW12.2
unnamed: D13.2 (A), SW13.2
unnamed: D14.2 (A), SW14.2
unnamed: D15.2 (A), SW15.2
unnamed: D16.2 (A), SW16.2
unnamed: D17.2 (A), SW17.2
unnamed: D18.2 (A), SW18.2
unnamed: D19.2 (A), SW19.2
unnamed: D20.2 (A), SW20.2
unnamed: D21.2 (A), SW21.2
unnamed: D22.2 (A), SW22.2
unnamed: D23.2 (A), SW23.2
unnamed: D24.2 (A), SW24.2
unnamed: D25.2 (A), SW25.2
unnamed: D26.2 (A), SW26.2
unnamed: D27.2 (A), SW27.2
unnamed: D28.2 (A), SW28.2
unnamed: D29.2 (A), SW29.2
unnamed: D30.2 (A), SW30.2
unnamed: D31.2 (A), SW31.2
unnamed: D32.2 (A), SW32.2
unnamed: D33.2 (A), SW33.2
unnamed: D34.2 (A), SW34.2
unnamed: D35.2 (A), SW35.2
unnamed: D36.2 (A), SW36.2
unnamed: D37.2 (A), SW37.2
unnamed: D38.2 (A), SW38.2
unnamed: D39.2 (A), SW39.2
unnamed: D40.2 (A), SW40.2
unnamed: D41.2 (A), SW41.2
unnamed: D42.2 (A), SW42.2
unnamed: D43.2 (A), SW43.2
unnamed: D44.2 (A), SW44.2
unnamed: D45.2 (A), SW45.2
unnamed: D46.2 (A), SW46.2
unnamed: D47.2 (A), SW47.2
unnamed: D48.2 (A), SW48.2
unnamed: D49.2 (A), SW49.2
unnamed: D50.2 (A), SW50.2
unnamed: D51.2 (A), SW51.2
unnamed: D52.2 (A), SW52.2
unnamed: D53.2 (A), SW53.2
unnamed: D54.2 (A), SW54.2
unnamed: D55.2 (A), SW55.2
unnamed: D56.2 (A), SW56.2
unnamed: D57.2 (A), SW57.2
unnamed: D58.2 (A), SW58.2
unnamed: D59.2 (A), SW59.2
unnamed: D60.2 (A), SW60.2
unnamed: D61.2 (A), SW61.2
R0: A1.4 (GPIO2), D1.1 (K), D2.1 (K), D3.1 (K), D4.1 (K), D5.1 (K), D6.1 (K), D7.1 (K), D8.1 (K), D9.1 (K), D10.1 (K), D11.1 (K), D12.1 (K), D13.1 (K), D14.1 (K)
R1: A1.5 (GPIO3), D15.1 (K), D16.1 (K), D17.1 (K), D18.1 (K), D19.1 (K), D20.1 (K), D21.1 (K), D22.1 (K), D23.1 (K), D24.1 (K), D25.1 (K), D26.1 (K), D27.1 (K), D28.1 (K)
R2: A1.6 (GPIO4), D29.1 (K), D30.1 (K), D31.1 (K), D32.1 (K), D33.1 (K), D34.1 (K), D35.1 (K), D36.1 (K), D37.1 (K), D38.1 (K), D39.1 (K), D40.1 (K), D41.1 (K)
R3: A1.7 (GPIO5), D50.1 (K), D51.1 (K), D52.1 (K), D53.1 (K), D54.1 (K), D55.1 (K), D56.1 (K), D57.1 (K), D58.1 (K), D59.1 (K), D60.1 (K), D61.1 (K)
R4: A1.9 (GPIO6), D42.1 (K), D43.1 (K), D44.1 (K), D45.1 (K), D46.1 (K), D47.1 (K), D48.1 (K), D49.1 (K)
S1: A1.31 (GPIO26_ADC0), SW62.S1
S2: A1.2 (GPIO1), SW63.S1



Board: 2 copper layers, 321.0 x 101.0 mm, 130 parts (61 on the bottom side), 88 nets.

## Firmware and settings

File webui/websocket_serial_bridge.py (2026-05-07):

#!/usr/bin/env python3
"""
WebSocket-to-Serial bridge for FlexAudioLink configuration GUI.
Allows Firefox/Safari users to communicate with the dongle via WebSocket
when WebSerial is not available.

Usage:
    pip install pyserial websockets
    python websocket_serial_bridge.py                  # auto-detect or interactive select
    python websocket_serial_bridge.py /dev/ttyACM0     # specify port directly
    python websocket_serial_bridge.py --baud 921600    # custom baud rate
    python websocket_serial_bridge.py --mock            # run with simulated device (no hardware)
"""

import argparse
import asyncio
import json
import random
import sys
from datetime import datetime

import serial
import serial.tools.list_ports
import websockets

# ANSI colors for terminal traffic display
C_TX = "\033[36m"   # cyan  — GUI → Device
C_RX = "\033[33m"   # yellow — Device → GUI
C_RST = "\033[0m"

# USB VID/PID for the FlexAudioLink dongle
DONGLE_VID = 0x1FC9
DONGLE_PID = 0x00A2
WS_HOST = "localhost"
WS_PORT = 8765
DEFAULT_BAUD = 115200


def list_serial_ports():
    """List all available serial ports with details."""
    ports = serial.tools.list_ports.comports()
    return sorted(ports, key=lambda p: p.device)


def find_dongle():
    """Auto-detect dongle by USB VID/PID."""
    for port in serial.tools.list_ports.comports():
        if port.vid == DONGLE_VID and port.pid == DONGLE_PID:
            return port.device
    return None


def select_port_interactive():
    """Let the user pick a serial port from a numbered list."""
    ports = list_serial_ports()
    if not ports:
        print("No serial ports found.")
        return None

    print("\nAvailable serial ports:")
    for i, port in enumerate(ports):
        vid_pid = ""
        if port.vid is not None:
            vid_pid = f"  [{port.vid:04X}:{port.pid:04X}]"
        desc = port.description or ""
        marker = " <-- FlexAudioLink dongle" if (port.vid == DONGLE_VID and port.pid == DONGLE_PID) else ""
        print(f"  {i + 1}) {port.device}  {desc}{vid_pid}{marker}")

    print()
    while True:
        try:
            choice = input(f"Select port [1-{len(ports)}]: ").strip()
            idx = int(choice) - 1
            if 0 <= idx < len(ports):
                return ports[idx].device
        except (ValueError, EOFError):
            pass
        print("Invalid selection, try again.")


def resolve_port(port_arg):
    """Resolve which serial port to use: argument > auto-detect > interactive."""
    if port_arg:
        return port_arg

    auto = find_dongle()
    if auto:
        print(f"Auto-detected FlexAudioLink dongle: {auto}")
        return auto

    print("FlexAudioLink dongle not auto-detected (VID:PID {0:04X}:{1:04X}).".format(DONGLE_VID, DONGLE_PID))
    return select_port_interactive()


class MockDevice:
    """Simulated device for GUI testing without real hardware."""

    MODE_AUDIO_IO = {
        'usb': 'wired',
        'prop_dongle': 'usb',
        'prop_headset': 'codec',
    }

    DEFAULT_STATE = {
        # Audio — Speaker
        'sample_rate_spk': '48000', 'bit_width_spk': '16',
        'channels_spk': 'stereo', 'codec_spk': 'pcm',
        'volume': '80', 'sidetone': '0',
        # Audio — Mic
        'sample_rate_mic': '48000', 'bit_width_mic': '16',
        'channels_mic': 'mono', 'codec_mic': 'pcm',
        'mic_gain': '12', 'mic_mute': 'off',
        # Radio
        'phy_rate': '4', 'tx_power': '0', 'fhss_exclusion': 'none',
        'payload_ms_dl': '1', 'payload_ms_ul': '1', 'jitter_buffer_ms': '10',
        # Mode
        'mode': 'prop_dongle',
        # Device
        'audio_io': 'usb', 'device_addr': 'D0D0D0D0', 'peer_addr': 'A1A1A1A1',
        'auto_sleep': '10', 'low_battery_threshold': '10',
        # EQ
        'eq0': '100,0', 'eq1': '400,0', 'eq2': '1000,0',
        'eq3': '4000,0', 'eq4': '10000,0',
    }

    # Group config keys for structured 'get all' output
    GROUPS = [
        ('[audio]', ['sample_rate_spk', 'bit_width_spk', 'channels_spk', 'codec_spk',
                     'volume', 'sidetone', 'sample_rate_mic', 'bit_width_mic',
                     'channels_mic', 'codec_mic', 'mic_gain', 'mic_mute']),
        ('[radio]', ['phy_rate', 'tx_power', 'fhss_exclusion',
                     'payload_ms_dl', 'payload_ms_ul', 'jitter_buffer_ms']),
        ('[mode]', ['mode']),
        ('[device]', ['audio_io', 'device_addr', 'peer_addr', 'auto_sleep',
                      'low_battery_threshold']),
        ('[eq]', ['eq0', 'eq1', 'eq2', 'eq3', 'eq4']),
    ]

    def __init__(self):
        self.state = dict(self.DEFAULT_STATE)
        self.echo = True
        self.status_interval_ms = 0  # 0 = off
        # Counters for status push
        self._tx = 0
        self._rx = 0
        self._lost = 0

    def handle_line(self, line):
        """Process a command line and return a list of response lines."""
        line = line.strip()
        if not line:
            return []

        parts = line.split()
        cmd = parts[0].lower()

        if cmd == 'echo':
            if len(parts) > 1 and parts[1].lower() == 'off':
                self.echo = False
            else:
                self.echo = True
            return ['OK echo']

        if cmd == 'status':
            if len(parts) >= 3 and parts[1].lower() == 'on':
                try:
                    self.status_interval_ms = int(parts[2])
                except ValueError:
                    return [f'ERR status invalid_interval']
                return ['OK status']
            elif len(parts) >= 2 and parts[1].lower() == 'off':
                self.status_interval_ms = 0
                return ['OK status']
            return ['ERR status bad_args']

        if cmd == 'get':
            if len(parts) >= 2 and parts[1].lower() == 'all':
                return self._get_all()
            if len(parts) >= 2:
                key = parts[1]
                if key in self.state:
                    return [f'{key}={self.state[key]}']
                return [f'ERR {key} unknown_param']
            return ['ERR get missing_param']

        if cmd == 'set':
            if len(parts) >= 3:
                key = parts[1]
                value = ' '.join(parts[2:])
                if key in ('save_config', 'load_config'):
                    return [f'OK {key}']
                if key == 'mode':
                    if value not in self.MODE_AUDIO_IO:
                        return ['ERR mode invalid_value']
                    self.state['mode'] = value
                    self.state['audio_io'] = self.MODE_AUDIO_IO[value]
                    return [f'OK mode={value}']
                if key in self.state:
                    self.state[key] = value
                    return [f'OK {key}={value}']
                # EQ: 'set eq <band> <freq> <gain>'
                if key == 'eq' and len(parts) >= 5:
                    band = parts[2]
                    eq_key = f'eq{band}'
                    if eq_key in self.state:
                        self.state[eq_key] = f'{parts[3]},{parts[4]}'
                        return [f'OK eq={self.state[eq_key]}']
                return [f'ERR {key} unknown_param']
            return ['ERR set missing_args']

        if cmd == 'reset':
            return ['OK reset']

        if cmd == 'save_config':
            return ['OK save_config']

        if cmd == 'load_config':
            return self._get_all()

        return [f'ERR {cmd} unknown_command']

    def _get_all(self):
        """Return all config as grouped key=value lines."""
        lines = []
        for header, keys in self.GROUPS:
            lines.append(header)
            for key in keys:
                lines.append(f'{key}={self.state[key]}')
        return lines

    def status_line(self):
        """Generate a periodic status push line with slight jitter."""
        self._tx += random.randint(8, 12)
        self._rx += random.randint(8, 12)
        self._lost += (1 if random.random() < 0.05 else 0)
        rssi = -45 + random.randint(-5, 5)
        bat = max(0, min(100, 85 + random.randint(-1, 1)))
        loss = round(random.uniform(0, 0.5), 1)
        return (f'#S rssi={rssi} bat={bat} loss={loss} conn=yes '
                f'tx={self._tx} rx_ok={self._rx} lost={self._lost} '
                f'urun=0 orun=0 cerr=0 fw=0.1.0')


class Bridge:
    def __init__(self, port, baud, ws_port=WS_PORT, verbose=False, mock=False):
        self.port = port
        self.baud = baud
        self.ws_port = ws_port
        self.verbose = verbose
        self.mock = mock
        self.mock_device = MockDevice() if mock else None
        self.ser = None
        self.ws_client = None
        self._read_task = None

    def _log_traffic(self, direction, line):
        """Print traffic to terminal. direction: 'TX' (GUI→Device) or 'RX' (Device→GUI)."""
        if not self.verbose:
            return
        ts = datetime.now().strftime("%H:%M:%S.%f")[:-3]
        color = C_TX if direction == "TX" else C_RX
        print(f"{color}{ts} {direction} {line}{C_RST}")

    def connect_serial(self):
        try:
            self.ser = serial.Serial(self.port, self.baud, timeout=0.1)
            print(f"Serial connected: {self.port} @ {self.baud} baud")
            return True
        except serial.SerialException as e:
            print(f"Serial error: {e}")
            return False

    def disconnect_serial(self):
        if self.ser and self.ser.is_open:
            self.ser.close()
            self.ser = None
            print("Serial disconnected")

    async def serial_read_loop(self):
        """Read lines from serial and forward to WebSocket client."""
        loop = asyncio.get_event_loop()
        buffer = ""
        while self.ser and self.ser.is_open:
            try:
                data = await loop.run_in_executor(None, self.ser.readline)
                if data:
                    buffer += data.decode("utf-8", errors="replace")
                    while "\n" in buffer:
                        line, buffer = buffer.split("\n", 1)
                        line = line.strip()
                        if not line:
                            continue
                        self._log_traffic("RX", line)
                        if self.ws_client:
                            try:
                                await self.ws_client.send(line)
                            except websockets.ConnectionClosed:
                                break
                else:
                    await asyncio.sleep(0.01)
            except (serial.SerialException, OSError):
                print("Serial read error, attempting reconnect...")
                self.disconnect_serial()
                while not self.connect_serial():
                    await asyncio.sleep(2)

    async def mock_status_loop(self):
        """Periodically send status push lines from the mock device."""
        while True:
            if self.mock_device.status_interval_ms > 0 and self.ws_client:
                line = self.mock_device.status_line()
                self._log_traffic("RX", line)
                try:
                    await self.ws_client.send(line)
                except websockets.ConnectionClosed:
                    break
                await asyncio.sleep(self.mock_device.status_interval_ms / 1000)
            else:
                await asyncio.sleep(0.1)

    async def handle_ws(self, websocket):
        """Handle a single WebSocket client connection."""
        if self.ws_client:
            print("Rejecting second client — only one connection allowed")
            await websocket.close(1008, "Only one client allowed")
            return

        self.ws_client = websocket
        print(f"WebSocket client connected: {websocket.remote_address}")

        if self.mock:
            # Mock mode — no serial needed
            self._read_task = asyncio.create_task(self.mock_status_loop())
        else:
            # Ensure serial is connected
            if not self.ser or not self.ser.is_open:
                if not self.connect_serial():
                    await websocket.send(
                        json.dumps({"cmd": "error", "message": f"Cannot open {self.port}"})
                    )

            # Start serial read loop
            self._read_task = asyncio.create_task(self.serial_read_loop())

        try:
            async for message in websocket:
                line = message.strip()
                self._log_traffic("TX", line)

                if self.mock:
                    # Route through mock device
                    responses = self.mock_device.handle_line(line)
                    for resp in responses:
                        self._log_traffic("RX", resp)
                        await websocket.send(resp)
                else:
                    # Forward to serial
                    if self.ser and self.ser.is_open:
                        try:
                            self.ser.write((line + "\n").encode("utf-8"))
                        except serial.SerialException:
                            print("Serial write error")
                            await websocket.send(
                                json.dumps(
                                    {"cmd": "error", "message": "Serial write failed"}
                                )
                            )
        except websockets.ConnectionClosed:
            pass
        finally:
            print("WebSocket client disconnected")
            self.ws_client = None
            if self._read_task:
                self._read_task.cancel()
                try:
                    await self._read_task
                except asyncio.CancelledError:
                    pass

    async def run(self):
        print(f"\nFlexAudioLink Bridge — ws://{WS_HOST}:{self.ws_port}")
        if self.mock:
            print("Mode: MOCK DEVICE (no serial hardware)")
        else:
            print(f"Serial: {self.port} @ {self.baud} baud")
        if self.verbose:
            print(f"Traffic logging: {C_TX}TX (GUI→Device){C_RST}  {C_RX}RX (Device→GUI){C_RST}")
        print("Waiting for WebSocket client...\n")
        async with websockets.serve(self.handle_ws, WS_HOST, self.ws_port):
            await asyncio.Future()  # Run forever


def main():
    parser = argparse.ArgumentParser(
        description="FlexAudioLink WebSocket-to-Serial bridge"
    )
    parser.add_argument(
        "port", nargs="?", default=None,
        help="Serial port (e.g. /dev/ttyACM0, COM3). Omit to auto-detect or choose interactively."
    )
    parser.add_argument(
        "--baud", type=int, default=DEFAULT_BAUD,
        help=f"Baud rate (default: {DEFAULT_BAUD})"
    )
    parser.add_argument(
        "--ws-port", type=int, default=WS_PORT,
        help=f"WebSocket port (default: {WS_PORT})"
    )
    parser.add_argument(
        "-v", "--verbose", action="store_true",
        help="Show serial traffic in terminal (TX=GUI→Device, RX=Device→GUI)"
    )
    parser.add_argument(
        "-m", "--mock", action="store_true",
        help="Run with simulated device (no serial hardware needed)"
    )
    parser.add_argument(
        "--list", action="store_true",
        help="List available serial ports and exit"
    )
    args = parser.parse_args()

    if args.list:
        ports = list_serial_ports()
        if not ports:
            print("No serial ports found.")
        else:
            for port in ports:
                vid_pid = ""
                if port.vid is not None:
                    vid_pid = f"  [{port.vid:04X}:{port.pid:04X}]"
                print(f"  {port.device}  {port.description or ''}{vid_pid}")
        sys.exit(0)

    if args.mock:
        port = None
    else:
        port = resolve_port(args.port)
        if not port:
            print("No port selected. Exiting.")
            sys.exit(1)

    ws_port = args.ws_port

    bridge = Bridge(port, args.baud, ws_port, verbose=args.verbose, mock=args.mock)
    try:
        asyncio.run(bridge.run())
    except KeyboardInterrupt:
        print("\nBridge stopped")
        bridge.disconnect_serial()
        sys.exit(0)


if __name__ == "__main__":
    main()

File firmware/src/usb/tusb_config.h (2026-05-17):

#pragma once

#ifdef __cplusplus
extern "C" {
#endif

#ifndef CFG_TUSB_MCU
#define CFG_TUSB_MCU          OPT_MCU_NRF54
#endif

#ifndef CFG_TUSB_OS
#define CFG_TUSB_OS           OPT_OS_ZEPHYR
#endif

#ifndef BOARD_TUD_RHPORT
#define BOARD_TUD_RHPORT      0
#endif

#ifndef BOARD_TUD_MAX_SPEED
#define BOARD_TUD_MAX_SPEED   OPT_MODE_HIGH_SPEED
#endif

#ifndef CFG_TUSB_DEBUG
#define CFG_TUSB_DEBUG        0
#endif

#include "audio/audio_config.h"

#define CFG_TUD_ENABLED       1
#define CFG_TUH_ENABLED       0

#define CFG_TUD_MAX_SPEED     BOARD_TUD_MAX_SPEED

#ifndef CFG_TUSB_MEM_SECTION
#define CFG_TUSB_MEM_SECTION
#endif

#ifndef CFG_TUSB_MEM_ALIGN
#define CFG_TUSB_MEM_ALIGN    __attribute__((aligned(4)))
#endif

#define CFG_TUD_ENDPOINT0_SIZE    64

#define CFG_TUD_CDC               1
#define CFG_TUD_MSC               0
#define CFG_TUD_HID               0
#define CFG_TUD_MIDI              0
#define CFG_TUD_AUDIO             1
#define CFG_TUD_VENDOR            0

#define CFG_TUD_AUDIO_ENABLE_INTERRUPT_EP                            1
#define CFG_TUD_AUDIO_FUNC_1_N_FORMATS                               1
#define CFG_TUD_AUDIO_FUNC_1_MAX_SAMPLE_RATE                         AUDIO_SAMPLE_RATE_HZ
#define CFG_TUD_AUDIO_FUNC_1_N_CHANNELS_TX                           AUDIO_MIC_CHANNELS
#define CFG_TUD_AUDIO_FUNC_1_N_CHANNELS_RX                           AUDIO_SPK_CHANNELS
#define CFG_TUD_AUDIO_FUNC_1_FORMAT_1_N_BYTES_PER_SAMPLE_TX          AUDIO_BYTES_PER_SAMPLE
#define CFG_TUD_AUDIO_FUNC_1_FORMAT_1_RESOLUTION_TX                  AUDIO_BITS_PER_SAMPLE
#define CFG_TUD_AUDIO_FUNC_1_FORMAT_1_N_BYTES_PER_SAMPLE_RX          AUDIO_BYTES_PER_SAMPLE
#define CFG_TUD_AUDIO_FUNC_1_FORMAT_1_RESOLUTION_RX                  AUDIO_BITS_PER_SAMPLE

#define CFG_TUD_AUDIO_ENABLE_EP_IN                                   1
#define CFG_TUD_AUDIO10_FUNC_1_FORMAT_1_EP_SZ_IN                     \
	TUD_AUDIO_EP_SIZE(false, CFG_TUD_AUDIO_FUNC_1_MAX_SAMPLE_RATE, \
			  CFG_TUD_AUDIO_FUNC_1_FORMAT_1_N_BYTES_PER_SAMPLE_TX, \
			  CFG_TUD_AUDIO_FUNC_1_N_CHANNELS_TX)
#define CFG_TUD_AUDIO20_FUNC_1_FORMAT_1_EP_SZ_IN                     \
	TUD_AUDIO_EP_SIZE(true, CFG_TUD_AUDIO_FUNC_1_MAX_SAMPLE_RATE,  \
			  CFG_TUD_AUDIO_FUNC_1_FORMAT_1_N_BYTES_PER_SAMPLE_TX, \
			  CFG_TUD_AUDIO_FUNC_1_N_CHANNELS_TX)
#define CFG_TUD_AUDIO_FUNC_1_EP_IN_SZ_MAX                            \
	TU_MAX(CFG_TUD_AUDIO10_FUNC_1_FORMAT_1_EP_SZ_IN,              \
	       CFG_TUD_AUDIO20_FUNC_1_FORMAT_1_EP_SZ_IN)
#define CFG_TUD_AUDIO_FUNC_1_EP_IN_SW_BUF_SZ                         \
	TU_MAX(4 * CFG_TUD_AUDIO10_FUNC_1_FORMAT_1_EP_SZ_IN,          \
	       32 * CFG_TUD_AUDIO20_FUNC_1_FORMAT_1_EP_SZ_IN)

#define CFG_TUD_AUDIO_ENABLE_EP_OUT                                  1
#define CFG_TUD_AUDIO10_FUNC_1_FORMAT_1_EP_SZ_OUT                    \
	TUD_AUDIO_EP_SIZE(false, CFG_TUD_AUDIO_FUNC_1_MAX_SAMPLE_RATE, \
			  CFG_TUD_AUDIO_FUNC_1_FORMAT_1_N_BYTES_PER_SAMPLE_RX, \
			  CFG_TUD_AUDIO_FUNC_1_N_CHANNELS_RX)
#define CFG_TUD_AUDIO20_FUNC_1_FORMAT_1_EP_SZ_OUT                    \
	TUD_AUDIO_EP_SIZE(true, CFG_TUD_AUDIO_FUNC_1_MAX_SAMPLE_RATE,  \
			  CFG_TUD_AUDIO_FUNC_1_FORMAT_1_N_BYTES_PER_SAMPLE_RX, \
			  CFG_TUD_AUDIO_FUNC_1_N_CHANNELS_RX)
#define CFG_TUD_AUDIO_FUNC_1_EP_OUT_SZ_MAX                           \
	TU_MAX(CFG_TUD_AUDIO10_FUNC_1_FORMAT_1_EP_SZ_OUT,             \
	       CFG_TUD_AUDIO20_FUNC_1_FORMAT_1_EP_SZ_OUT)
#define CFG_TUD_AUDIO_FUNC_1_EP_OUT_SW_BUF_SZ                        \
	TU_MAX(AUDIO_SPK_BUFFER_BYTES,                                 \
	       TU_MAX(4 * CFG_TUD_AUDIO10_FUNC_1_FORMAT_1_EP_SZ_OUT,   \
		      32 * CFG_TUD_AUDIO20_FUNC_1_FORMAT_1_EP_SZ_OUT))

#define CFG_TUD_AUDIO_ENABLE_FEEDBACK_EP                             0

#define CFG_TUD_CDC_NOTIFY        1
#define CFG_TUD_CDC_RX_BUFSIZE    (TUD_OPT_HIGH_SPEED ? 512 : 64)
#define CFG_TUD_CDC_TX_BUFSIZE    (TUD_OPT_HIGH_SPEED ? 512 : 64)
#define CFG_TUD_CDC_EP_BUFSIZE    (TUD_OPT_HIGH_SPEED ? 512 : 64)
#define CFG_TUD_CDC_RX_EPSIZE     (TUD_OPT_HIGH_SPEED ? 512 : 64)
#define CFG_TUD_CDC_TX_EPSIZE     (TUD_OPT_HIGH_SPEED ? 512 : 64)

#ifdef __cplusplus
}
#endif

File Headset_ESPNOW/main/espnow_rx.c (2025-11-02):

    
// File: espnow_rx.c
#include "freertos/FreeRTOS.h"
#include "freertos/ringbuf.h"
#include "esp_log.h"
#include "esp_now.h"
#include "esp_wifi.h"
#include "esp_mac.h"
#include "nvs_flash.h"
#include "driver/gpio.h"
#include "driver/i2s_std.h"


static const char *TAG = "ESPNOW_RX";

// ================== CONFIGURATION ==================
// Set the GPIO pin to toggle on receive
#define GPIO_OUTPUT_PIN     GPIO_NUM_15

// MAC address of the Dongle (TX)
static uint8_t peer_mac_address[] = {0x40, 0x4C, 0xCA, 0x56, 0x26, 0xAC};

// I2S port and GPIOs
#define I2S_NUM         (0)
#define I2S_MCK_IO      23
#define I2S_BCK_IO      20
#define I2S_WS_IO       3
#define I2S_DO_IO       2
#define I2S_DI_IO       5 // (unused for now)

// I2S PCM settings
#define I2S_SAMPLE_RATE     48000   // 48 kHz
#define I2S_CHANNEL_NUM     2       // 2 Channels for stereo audio
#define I2S_BITS_PER_SAMPLE 16      // 16 Bit

// Audio buffer settings
#define BUFFER_DURATION_MS 40 
#define BYTES_PER_SAMPLE (I2S_BITS_PER_SAMPLE / 8)
#define SAMPLES_PER_MS (I2S_SAMPLE_RATE / 1000)
#define AUDIO_BUFFER_SIZE (SAMPLES_PER_MS * BYTES_PER_SAMPLE * I2S_CHANNEL_NUM * BUFFER_DURATION_MS)
#define PLAYBACK_START_THRESHOLD (AUDIO_BUFFER_SIZE / 2) // Buffer fill state threshold

// ===================================================

// Define the same data structure to interpret the packet
typedef struct {
    uint32_t count;         // 2^32 packets are about 348 days of audio playback before overrun happens
    uint8_t  payload[1344]; // 7ms audio @ 48kHz Stereo 16 Bit
} audio_packet_t;


// Global Handles
static i2s_chan_handle_t i2s_tx_handle = NULL;
static RingbufHandle_t audio_ring_buffer = NULL;


// Callback function for when a packet is received
void on_data_received(const esp_now_recv_info_t *recv_info, const uint8_t *incoming_data, int len) {
    // Set GPIO HIGH immediately upon reception
    // gpio_set_level(GPIO_OUTPUT_PIN, 1);
    // gpio_set_level(GPIO_OUTPUT_PIN, 0);

    static uint32_t last_packet_count = UINT32_MAX; // UINT32_MAX indicates no package was previously received.
    static uint32_t packets_lost_total = 0;
    
    if (len != sizeof(audio_packet_t)) {
        ESP_LOGE(TAG, "Received packet of unexpected size from " MACSTR, MAC2STR(recv_info->src_addr));
        return;
    }

    audio_packet_t received_packet;
    memcpy(&received_packet, incoming_data, sizeof(received_packet));

    // Check for packet loss
    if (last_packet_count != UINT32_MAX && received_packet.count > last_packet_count + 1) {
        uint32_t packets_missed = received_packet.count - (last_packet_count + 1);
        packets_lost_total += packets_missed;
        ESP_LOGW(TAG, "Packet loss! Missed %lu packets. Total lost: %lu", packets_missed, packets_lost_total);
        // TODO: Handle packet loss here!
    }
    last_packet_count = received_packet.count;

    // Send received audio data to the ring buffer
    // Note: Using a timeout of 0, so we don't block the callback.
    // If the buffer is full, data is dropped.
    BaseType_t result = xRingbufferSend(audio_ring_buffer, received_packet.payload, sizeof(received_packet.payload), 0);
    if (result != pdTRUE) {
        if(received_packet.count%1000 == 0){
            ESP_LOGE(TAG, "Couldnt write to audio buffer (overflow or timeout). Dropping packet.");
        }
    }
    else{
        if(received_packet.count%1000 == 0){
        UBaseType_t buffered_size = 0;
        vRingbufferGetInfo(audio_ring_buffer, NULL, NULL, NULL, NULL, &buffered_size);
        ESP_LOGI(TAG, "Put %d bytes into buf, current bytes in buf: %lu", sizeof(received_packet.payload), (unsigned long) buffered_size);
        }
    }
    
    // if (received_packet.count%1000 == 0) {
    //         ESP_LOGI(TAG, "len: %d cnt: #%lu src: " MACSTR, len, received_packet.count, MAC2STR(recv_info->src_addr));
    // }
}

static esp_err_t i2s_driver_init(void) {
    i2s_chan_config_t chan_cfg = I2S_CHANNEL_DEFAULT_CONFIG(I2S_NUM_AUTO, I2S_ROLE_MASTER);
    ESP_ERROR_CHECK(i2s_new_channel(&chan_cfg, &i2s_tx_handle, NULL));

    i2s_std_config_t std_cfg = {
        .clk_cfg = I2S_STD_CLK_DEFAULT_CONFIG(I2S_SAMPLE_RATE),
        .slot_cfg = I2S_STD_PHILIPS_SLOT_DEFAULT_CONFIG(I2S_BITS_PER_SAMPLE, I2S_SLOT_MODE_STEREO),
        .gpio_cfg = {
            .mclk = I2S_MCK_IO,
            .bclk = I2S_BCK_IO,
            .ws = I2S_WS_IO,
            .dout = I2S_DO_IO,
            .din = I2S_DI_IO,
            .invert_flags = {
                .mclk_inv = false,
                .bclk_inv = false,
                .ws_inv = false,
            },
        },
    };
    
    ESP_ERROR_CHECK(i2s_channel_init_std_mode(i2s_tx_handle, &std_cfg));
    return ESP_OK;
}
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

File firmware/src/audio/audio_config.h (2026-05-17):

#pragma once

#define AUDIO_SAMPLE_RATE_HZ          48000U
#define AUDIO_BYTES_PER_SAMPLE        2U
#define AUDIO_BITS_PER_SAMPLE         (AUDIO_BYTES_PER_SAMPLE * 8U)

#define AUDIO_SPK_CHANNELS            2U
#define AUDIO_MIC_CHANNELS            1U
#define AUDIO_I2S_CHANNELS            2U

#define AUDIO_SPK_BYTES_PER_FRAME     (AUDIO_SPK_CHANNELS * AUDIO_BYTES_PER_SAMPLE)
#define AUDIO_MIC_BYTES_PER_FRAME     (AUDIO_MIC_CHANNELS * AUDIO_BYTES_PER_SAMPLE)
#define AUDIO_I2S_BYTES_PER_FRAME     (AUDIO_I2S_CHANNELS * AUDIO_BYTES_PER_SAMPLE)

#define AUDIO_SPK_BYTES_PER_MS        ((AUDIO_SAMPLE_RATE_HZ / 1000U) * AUDIO_SPK_BYTES_PER_FRAME)
#define AUDIO_MIC_BYTES_PER_MS        ((AUDIO_SAMPLE_RATE_HZ / 1000U) * AUDIO_MIC_BYTES_PER_FRAME)
#define AUDIO_I2S_BYTES_PER_MS        ((AUDIO_SAMPLE_RATE_HZ / 1000U) * AUDIO_I2S_BYTES_PER_FRAME)

#define AUDIO_SPK_TARGET_MS           5U
#define AUDIO_SPK_BUFFER_MS           (AUDIO_SPK_TARGET_MS * 2U)
#define AUDIO_SPK_BUFFER_BYTES        (AUDIO_SPK_BUFFER_MS * AUDIO_SPK_BYTES_PER_MS)
#define AUDIO_SPK_TARGET_BYTES        (AUDIO_SPK_TARGET_MS * AUDIO_SPK_BYTES_PER_MS)

#define AUDIO_MIC_BUFFER_MS           10U
#define AUDIO_MIC_BUFFER_BYTES        (AUDIO_MIC_BUFFER_MS * AUDIO_MIC_BYTES_PER_MS)

#define AUDIO_PROP_PACKET_MS          1U
#define AUDIO_I2S_BLOCKS_PER_MS       2U
#define AUDIO_I2S_BLOCK_BYTES         (AUDIO_I2S_BYTES_PER_MS / AUDIO_I2S_BLOCKS_PER_MS)
#define AUDIO_I2S_SAMPLE_PAIRS_PER_BLOCK (AUDIO_I2S_BLOCK_BYTES / AUDIO_I2S_BYTES_PER_FRAME)

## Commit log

2023-04-26 Initial KiCad Upload
    [CC8531RHAT.stp, wireless-headset.kicad_pcb, wireless-headset.kicad_sch]
2024-04-26 Removed CC8531 KiCad files
    [CC8531RHAT.stp, wireless-headset.kicad_pcb, wireless-headset.kicad_sch]
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2025-11-13 Implement circular GDMA for I2S; Go back to using cmake tools, cubeCLT, etc.; Add fix_after_cubemx.py to .ioc Remove Drivers directory; Add pll.c/pll.h for reconfiguring the pll on runtime
2025-11-14 Register DMA callbacks; Enable i2s error interrupts; Move test data generation to audio.c; Inccrease spk_buf size
    [i2s.c, tusb_config.h]
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2025-11-18 Modify non cacheable ram section in linker script in order to force ep buffer to non cacheable region, this is needed because the DMA reads from this buffer; Re-enable D-Cache in main;
2025-11-29 Implement UAC2 asynchronous feedback for the speaker endpoint to decouple the device clock from the host USB clock.
    This change transitions the USB audio speaker stream from adaptive to asynchronous synchronization mode. A PI controller has been added to monitor the audio DMA buffer level and calculate the precise local sample rate. This rate is then reported back to the host via a newly added explicit feedback endpoint.
    The USB descriptors for UAC2 have been updated to define the asynchronous speaker data endpoint and the required feedback endpoint. This prevents buffer under/overruns caused by clock mismatches, improving overall audio quality and robustness.
    [tusb_config.h]
2025-11-30 Convert to standalone project structure.
    Decouples the project from the SDK's `freertos_hello` example directory to create a self-contained application.
    Key changes:
    - Build System: Updated `CMakeLists.txt` to calculate `PROJECT_BOARD_PORT_PATH` relative to the SDK root, allowing the SDK build scripts to correctly locate local board files.
    - Board Support: "Vendored" (copied) standard board definition files (`board`, `clock_config`, `pin_mux`, `peripherals`) from the SDK template into the local source directory.
    - SDK Compliance: Added `hardware_init.c` and `app.h` to satisfy the SDK's strict project segment requirements.
    - Config: Added `cm33_non_trustzone` to `prj.conf` to fix missing `po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
2025-11-30 Integrates the TinyUSB stack into the RW612 project to provide USB CDC (Virtual COM Port) capabilities.
    This commit includes:
    - Addition of TinyUSB configuration (tusb_config.h) and USB descriptor (usb_descriptors.c) files.
    - Updates to CMakeLists.txt to include TinyUSB source files, set up include paths, and rename the project to rw612_sw.
    - Modifications to hardware_init.c for TinyUSB interrupt handling.
    - Refactoring of main.c to initialize TinyUSB and create dedicated FreeRTOS tasks for USB device management and CDC application logic, demonstrating a dual CDC echo.
    - Minor VSCode settings update for file associations.
2025-12-06 - Add `FRDM-RW612.mex` MCUXpresso Config Tool configuration file. - Enable FLEXCOMM0 (I2S) with DMA support. - Configure Debug UART, SWD, and LED pins. - Regenerate `pin_mux`, `clock_config`, and `pe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
2025-12-06 Set LED GPIO initial states to true inside config tool configuration and regenerate code (true state turns the LED off).
2025-12-06 Change MCUXPresso Config Tool configuration: Init functions for DEBUG UART, SWD, and LED pins are now called by auto generated code inside BOARD_InitBootPins().
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2025-12-08 Implement I2S audio playback with DMA and USB feedback
    - MCUXpresso Config (.mex):
    - Clocks: Configure Audio PLL for ~12.288 MHz to support 48kHz sampling. Route Audio PLL to FLEXCOMM0 and MCLK. Disable default XTAL32K routing and enable MCLK output.
    - Peripherals: Enable FLEXCOMM0 (I2S) with DMA integration. Configure NVIC interrupts for DMA0 (Priority 3) and FLEXCOMM0 (Priority 5). Set up I2S TX DMA channel requests.
    - Pins: Route CLKCTL1 MCLK signal to pin L7 (GPIO_5) as output.
    - IRQs: Configure interrupts and their priorities and also configure the initialization to be auto-generated.
    - Audio Logic:
    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
2025-12-14 Add CDC descriptor; Add CDC device driver to cmakelists.txt; Remove 44.1kHz from UAC1 descriptor; Remove 44.1kHz from UAC2 sample rate array;
2025-12-16 Refactor audio pipeline: Improve synchronization and feedback
    Major overhaul of the audio task and feedback controller
    - Replaced static double-buffering with a dynamic, ring-buffer aware
    DMA queue mechanism.
    - Implemented a thread-safe `size_q` (Size Queue) to synchronize
    transfer sizes between the Task (Producer) and ISR (Consumer).
    - Added Exponential Moving Average (EMA) smoothing to the buffer level
    measurement to reject DMA consumption jitter.
    - Switched Feedback Controller from PI to P-Only logic and moved it to
    a dedicated task running at 100ms intervals for improved stability.
    - Added `MINIMUM_DMA_BLOCK_SIZE` check to prevent queue exhaustion
    caused by small memory fragme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
2025-12-16 CLI: Add Command Line Interface (CLI) module
    - Implement CLI over USB CDC using TinyUSB (`cli.c`, `cli.h`).
    - Architecture: Designed `cli_task` to handle command processing and echoing via a queue. This ensures thread safety for CDC writes and prevents blocking the USB task context.
    - Buffer Handling: Implemented `tud_cdc_rx_cb` to flush the CDC RX buffer if data is received without a newline, preventing buffer lockup on partial commands. Added a warning message when this occurs.
    - Features:
    - Implemented commands: `help`, `reset`, `echo`, `scan`.
    - Added `cli_print_formatted_json` helper with local buffering and bounds checking for safe printing of scan results.
2026-01-24 Move Wi-Fi related code to seperate files; Add minimal UDP sockets; Add temporary GPIOs for configuring wether device is uAP or STA;
2026-01-25 Implement app modes tracking the state of the application; Implement mode setting option to cli; Add CDC only descriptor and dynamically switch and reenumerate usb descriptors upon mode switch;
2026-01-31 Add udp audio FIFOs by just using tinyUSB's FIFO implementation; Implement helper functions for retrieving FIFO pointers; Implement audio reset function which is called on every mode change; spk_ff a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
2026-02-11 Force 20 MHz BW for AP; Add more error checking in wifi initalization; Disable RTS threshold, Disable Roaming; Remove Broadcast Address for latency reasons; Set UDP packet payload size to 240 bytes f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
    [tusb_config.h]
2026-02-12 Implement q_term.py tool for debugging purposes, allows to monitor and write to four USB serial devices simutaneously, also auto-reconnects based on USB descriptor serial number.
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2026-02-12 Add schematic, charging and protection circuit, buck-boost converter;
    [FlexAudioLink.kicad_pcb, FlexAudioLink.kicad_sch]
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2026-02-15 Add RW612 Symbol, HVQFN116 footprint & 3D Model; Organize schematic into two sheets with top level sheet;
    [FlexAudioLink.kicad_sch, Input_Charger_Power.kicad_sch, MCU.kicad_sch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]
2026-02-15 Redirect PRINTF() to log_print() inside log.c/log.h; Revert back to calling PRINTF(); Somewhat of a workaround to the SDK, the wifi driver depends on the debug console and calls PRINTF() so now every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
2026-02-17 Implement sample rate feedback via UDP; Change some priorities; Change back USB audio EP size;
2026-02-18 Change jitter buffer size from 8192 bytes ( ~42.7ms) to 2048 bytes (~10,7ms);
2026-02-18 Add Feedback Error calculation script for debugging/testing purposes;
    [fb_error_calc.py]
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2026-02-25 Split UDP task into tx/rx; Slightly change blink patterns; Remove timeout from audio_task, only wake on notify; Change I2S DMA block limits tp #defines; Improve audio_task conditional logic; Change c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
2026-03-08 Explicitly set nominal sample rate as feedback rate when host sets interface.
2026-03-08 Decrease wifi_drv_task_priority; Properly implement silent insertion on packet loss; Increase tx_udp_packet_counter even on failed sendto() calls;
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2026-04-09 Track current issues in unified TODO.MD
2026-04-13 - make next_tx_tick the single authoritative TX schedule state - allow headset RX-sync retiming of a pending slot without rewriting the TX packet - reject late TX schedule updates once pre-TX has sta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
    [radio_hw.c]
2026-04-16 Rework proprietary GFSK link timing and listen flow for ping-pong TDD;
    [radio_hw.c]
2026-04-18 Fix Prop GFSK initial startup by waiting for RX; Add deadline clamping, and add deadline-late diagnostics;
    [radio_hw.c]
2026-04-18 Fix status interpretation in webui and throughput script.
    [throughput.py]
2026-04-18 Fix mock status rx_ok field name;
    [websocket_serial_bridge.py]
2026-04-19 Fix NAU88L21 registers; Select different i2c pins; Add strerror();
    [i2s.c, nau88l21.c]
2026-04-25 refactor app control to unified profiles; add wired USB/I2S audio path; add PGFSK audio path scaffolding; add USB Audio stream handling and descriptors; update I2S TX queue accounting; refactor PGFSK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
2026-04-26 refactor wireless audio path into dongle/headset variants; rewrite I2S to FIFO-based driver with starvation recovery; remove I2S tone generator; add NAU88L21 FLL on-the-fly reconfiguration; switch US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
2026-04-26 Simplify audio_i2s thread; add error/state visibility; deepen TDM tx/rx queues to 16; add invariant asserts;
    [i2s.c]
2026-04-26 Remove resume semaphore for autonomous retry from i2s thread; add state logging; drop starvation detection; simplify path state transitions;
2026-04-28 Replace shared-state FIFO pointers with msgq-based I2S command interface; batch-fill TX before blocking on RX; remove dead duplicate activate/deactivate in headset path; drop unused set_fifo/rx_set_f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
    [audio_path_common.h, i2s.c]
2026-04-29 Use zephyr logging in audio_path_common; Replace combined level with fifo+pending in controller; Change I2S Thread priority;
    [audio_path_common.h, i2s.c]
2026-04-29 Reboot on profile change instead of live-switching paths; Remove audio_path_*_activate/deactivate, active flag, start/stop sems; Remove pgfsk_link_stop and role-swap purge; Spawn audio path and pgfsk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
2026-04-30 Simplify reboot-based profile changes; Lazily spawn linktest threads; Hide private audio controller helpers;
    [audio_path_common.h]
2026-04-30 Give headset path dedicated audio FIFOs; Initialize FIFO mutexes with osal_mutex_create; Keep USB device thread blocked in tud_task; Log missing USB audio FIFOs;
2026-05-01 Move PGFSK turn handling into radio_hw; Add RX/TX packet rings; Replace prepared TX with keepalive fallback;
    [radio_hw.c]
2026-05-01 Mark PGFSK keepalives by sequence; Set minimum keepalive payload; Add PHYEND GPIO probes; Update TDD spec;
2026-05-01 Remove RW612 firmware tree and submodule; Remove RW612 CI workflow; Strip RW612 symbol, footprint, and 3D model from hardware; Update README;
    [RW612HN_A2IMP.stp]
2026-05-01 Stop wired playback before sub-block underrun; Require fresh I2S activate after errors; Shorten audio controller log prefix;
    [i2s.c]
2026-05-02 Remove PFSK frame wrapper; Keep packet length as metadata plus payload; Use fixed wireless audio packet sizes; Rename packet data to payload; Simplify mono extraction;
    [audio_path_common.h, radio_core.c, radio_core.h]
2026-05-02 Move mono extraction into I2S RX path; Remove intermediate wired mic FIFO; Read headset mic as mono directly; Drop mic_overflow_bytes tracking;
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2026-05-03 Rename audio_path_ files and symbols to path_; Drop audio_ prefix from path-internal macros and types; Shorten wireless dongle/headset names;
    [path_common.h, path_dongle.c]
2026-05-03 Replace volatile bool boot flag with k_sem; Remove spin-wait from USB thread;
2026-05-03 Rename pfsk_radio_event to pfsk_session_event to resolve naming conflict with nRF RADIO peripheral events;
    [radio_core.c, radio_core.h]
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2026-05-13 Fix minor errors in use case diagram;
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2026-05-15 Rename PROP packet payload fields to data for improved clarity and avoiding confusion with PAYLOAD terminology of propietary 2.4 GHz radio;
    [path_common.h, path_dongle.c, radio_core.c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]
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2026-07-26 Update schematic; Add NAU88L21 schematic symbol;
    [Analog.kicad_sch, FlexAudioLink.kicad_sch, Input_Charger_Power.kicad_sch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]
